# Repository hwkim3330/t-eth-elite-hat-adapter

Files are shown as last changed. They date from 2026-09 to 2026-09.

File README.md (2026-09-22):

# T-ETH-Elite ↔ Raspberry Pi HAT adapter

Hardware that lets a **Raspberry Pi HAT** run on a **LilyGO T-ETH-Elite**
(ESP32-S3) instead of a Pi. Built for one specific HAT — TSN Lab's
`10BASE-T1S HAT` (Microchip LAN8651, [devicemart #15980354](https://www.devicemart.co.kr/goods/view?no=15980354)),
which is a Pi-only product — so that a 10BASE-T1S node can be an ESP32 rather
than a Raspberry Pi. Firmware side lives in
[esp32-t1s-bridge](https://github.com/hwkim3330/esp32-t1s-bridge).

```
   TSN Lab 10Base-T1S HAT  (LAN8651)
   ── adapter PCB ──                    pcb/
   LilyGO T-ETH-Elite  (ESP32-S3)
   ── printed tray ──                   case/
```

| | |
|---|---|
| `pcb/` | the adapter board — KiCad project, gerbers, BOM/CPL |
| `case/` | printed base tray for the Elite, generated and clearance-checked by script |
| `reference/` | LilyGo's own DXF and 3D models, plus the script that re-derives every dimension from them |
| [`pcb/GEOMETRY.md`](pcb/GEOMETRY.md) | **the single source of truth** — every measured number, with its provenance |

## The short version of why this exists

Plugging the HAT straight onto the T-ETH-Elite *almost* works, and the two
reasons it doesn't are worth stating up front:

1. **Electrically it already works.** LilyGo wired the Elite's 40-pin header to
   the standard Raspberry Pi GPIO assignment, pin for pin. No level shifting,
   no remapping, nothing to translate. The adapter carries no signal logic at
   all — the connection is the stacking header's own pins, straight through.
2. **The near mounting holes already line up.** Deriving where a Pi's
   header-end holes must sit, from the Elite's own header position, lands on
   the Elite's own bottom hole pair to within **0.005 mm**. Same holes.
3. **But the RJ45 is in the way.** The Elite's RJ45 stands **15.97 mm** off the
   PCB while its header pins stop at **10.10 mm**. Any flat, un-notched board
   dropped onto that header — which is exactly what a standard Pi HAT is — hits
   the jack 5.87 mm before it seats. LilyGo's own shields cut a notch for it.
4. **And the far mounting holes fall off the end.** A HAT's far holes sit 49 mm
   from the near pair, i.e. at y = 53.63 in the Elite's frame — past the Elite's
   own board edge at 49.19. There is nothing there to screw into.

Of those, only (4) genuinely needs a board. A tall enough stacking header would
lift a HAT clear of the RJ45 on its own — so the honest claim is not "a HAT
cannot sit on this board", it is that without the adapter a HAT sits on **two
screws at the connector end and nothing at the other**, with the Elite's BOOT
and RESET switches buried underneath it. On a board you push terminal-block
levers into, that is the difference between a fixture and a wobble.

## Provenance

Nothing here was scaled off a drawing by eye. The mounting holes, the 40-pin
grid, the outline notches and the component heights all come out of LilyGo's own
published DXF and 3D CAD, cross-checked three ways — and the hole pattern was
independently validated against a real board on a laser-cut plate in
`~/stl-model/acrylic-frame`. `reference/measure.py` re-derives the whole set
from the vendor files, so the numbers can be audited rather than trusted:

```bash
pip install --user ezdxf trimesh manifold3d py7zr
python3 reference/measure.py
```

The one number that is *not* from CAD is the HAT's own 58 × 49 hole pattern,
which is inferred from a product photo (method and error bars in
[`pcb/GEOMETRY.md`](pcb/GEOMETRY.md)). Only the placement of the adapter's two far holes depends
on it.

## Status

Designed, checked, **never built**. No board has been fabricated, nothing has
been printed, and no part of the stack has been assembled or powered. The
clearance check the case script runs is against LilyGo's model, not against a
real board. Read the "not verified" sections in [`pcb/README.md`](pcb/README.md) and
[`case/README.md`](case/README.md) before spending money.

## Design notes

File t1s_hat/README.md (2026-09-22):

# T1S HAT — LAN8651 10BASE-T1S for the LilyGO T-ETH-Elite

Our own 10BASE-T1S board for the [LilyGO
T-ETH-Elite](https://github.com/Xinyuan-LilyGO/LilyGO-T-ETH-Series)
(ESP32-S3), built around a **Microchip LAN8651** MAC-PHY. It replaces buying
TSN Lab's ready-made HAT: same chip, same host header, our schematic.

Two source files govern this board and **nothing here re-derives a number in
either of them**:

| file | governs |
|---|---|
| [`ELECTRICAL.md`](ELECTRICAL.md) | every component, value and pin-handling rule, each quoted from Microchip DS60001734F or AN1718 (DS60001718D) |
| [`../pcb/GEOMETRY.md`](../pcb/GEOMETRY.md) | outline, mounting holes, 2×20 grid — measured from LilyGo's own DXF and 3D CAD |

Everything is generated by [`make_t1s_hat.py`](make_t1s_hat.py), which emits
the symbol library, the two project-local footprints, the schematic and the
PCB, then reads the board back and asserts every mechanical feature against
`GEOMETRY.md`.

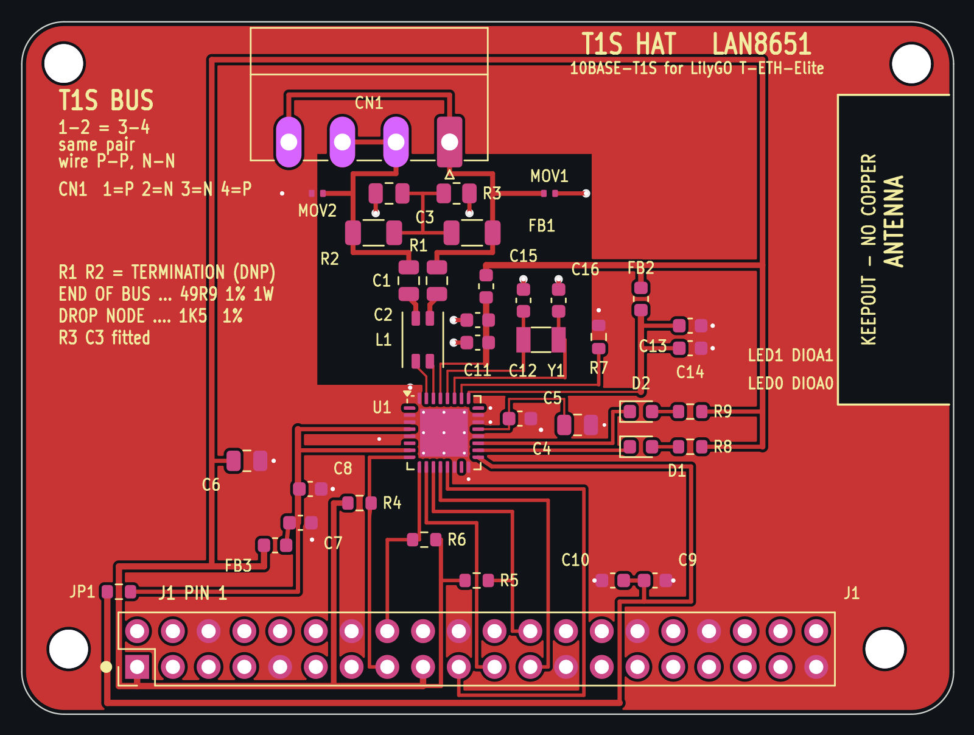
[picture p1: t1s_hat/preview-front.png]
front


## What it is

- **LAN8651**, 32-VQFN 5×5, single 3.3 V rail (the '51 regulates its own 1.8 V
  core, so there is no second regulator and no sequencing diode).
- **OPEN Alliance TC6 SPI** to the host on the same header pins TSN Lab's
  device-tree overlay uses, so their SDK and the mainline `microchip,lan8651`
  driver both work unmodified if this board is ever put on a Pi.
- **Bus interface network** in AN1718's MINIMAL BIN order: common-mode choke →
  AC coupling caps → termination → ESD → 4-way 3.81 mm pluggable terminal
  block, wired so the node taps a daisy chain.
- 38 parts, 4 of them deliberately unstuffed. One of the 38 is a 0 Ω jumper,
  and it is a design decision, not an accident — see below.

## The two parts that had to be chosen, not assumed

Both are drawn from their own data sheet into
[`fp/t1s_hat.pretty`](fp/t1s_hat.pretty), generated by `make_t1s_hat.py`
alongside the board, and the generator asserts the pad count and the overall
land size back out of the finished `.kicad_pcb`.

### L1 — TDK **ACT1210L-201-2P-TL00**, LCSC **C131444**

AN1718 names ACT1210D-131-2P-TL00, ACT1210E-241-2P-TL00 and Murata
DLW32MH241MX2, and says in the same breath that *"exact component part numbers
and parameters must be determined by the customer's unique application
requirements"* — they are examples. All three are **3.2 × 2.5 mm** (EIA 1210)
2-line chokes in the 130…240 µH @ 100 kHz band. The board previously sat on
KiCad's `Inductor_SMD:L_CommonMode_Wurth_WE-CNSW-1206`, a **3.2 × 1.6 mm**
land: same length, 0.9 mm too narrow, so the real part's terminals miss the
pads. KiCad ships no 4-terminal common-mode choke land in 3225.

The part fitted instead is the **ACT1210L-201-2P-TL00**: same ACT1210 package,
200 µH @ 100 kHz — inside the span AN1718's own examples cover — 70 mA,
5.5 Ω, AEC-Q200, and, unlike all three examples, **stocked at LCSC**
(C131444, ~$0.39/1k), which is where this board gets built.

Its land is `t1s_hat:L_CommonMode_TDK_ACT1210_3225`, drawn from TDK's ACT1210
data sheet "Layout recommendation" (drawing IND1512-9): **4.1 mm overall
across the pads with a 2.0 mm gap between the columns**, so each pad is
1.05 mm long on a 3.05 mm pitch, and **1.6 mm overall across the rows with a
0.4 mm gap**, so each pad is 0.60 mm wide on a 1.0 mm pitch. Body from the
same sheet: 3.2 ±0.2 long, 2.5 ±0.2 wide, 3.9 max over the terminals.

The symbol changed with it: the ACT1210's windings are **1-4 and 2-3**
(pin configuration and circuit diagram, same sheet), which is
`Device:L_Coupled_1423`, not the `…_1243` the 1206 Würth part needed.

### MOV1 / MOV2 — TDK **AVRH10C221KT1R5YA8**, LCSC **C2157827**

This is the part `ELECTRICAL.md` already names, and it is a **1005 [0402]**
chip varistor — 1.0 × 0.5 × 0.5 mm, 220 V V1mA, 70 V DC, **1.5 pF**, 25 kV per
IEC 61000-4-2. The board had it on `Resistor_SMD:R_1206_3216Metric`: three
size codes too big. It is now on `t1s_hat:Varistor_TDK_AVRH10_1005`, from the
recommended land pattern in TDK's automotive AVR chip-varistor catalogue
(pad 0.35…0.45 long, gap 0.3…0.5, pad 0.4…0.6 wide — the middle of each:
**0.40 long, 0.40 gap, 0.50 wide**). KiCad's `R_0402_1005Metric` is 0.54 ×
0.64 on a 1.02 mm pitch, outside all three ranges, which is why this one is
drawn here too. Both parts stay **DNP**; the land is now a real one.

## Three decisions that are not in ELECTRICAL.md / GEOMETRY.md

These were directed after those files were written. They are marked
`DIRECTED:` in the generator, and the reasoning is recorded here.

### 1. Two layers, not four

`ELECTRICAL.md` calls 4 layers non-negotiable because AN1718 wants TRXP/TRXN
as length-matched, impedance-controlled 50 Ω single-ended traces, and 50 Ω on
2-layer 1.6 mm FR4 needs a ~2.9 mm trace. The width figure is right; the
conclusion does not follow at this speed and length. 10BASE-T1S runs at
12.5 MBd with deliberately slow, EMC-shaped edges, and the run from the QFN to
the connector here is ~20 mm — electrically short, well under the length at
which a mismatch on a trace this short costs anything at these edge rates.
AN1718's 50 Ω line is a "do this and you are safe" recommendation, not a
threshold this design crosses.

**So the impedance is not controlled and is not claimed to be.** The pair is
0.35 mm over 1.51 mm of FR4, which is nowhere near 50 Ω. What buys the margin
back instead is layout discipline, and those rules are treated as hard:

- **All signal routing is on F.Cu. B.Cu is an uninterrupted ground pour.**
  The generator asserts this — `verify()` counts B.Cu tracks and the table
  prints `B.Cu signals … 0 tracks`.
- The only two interruptions in that plane are the antenna keepout and the
  all-layer void under the choke, both of which AN1718 or the Elite requires,
  and the choke void is sized to the choke — see inference 8.
- The one crossing that a single signal layer could not absorb is a **0 Ω
  jumper on F.Cu**, not a via pair through the plane. See below.
- TRXP/TRXN are short, symmetric about x = 29.0 from the QFN to the connector,
  and carry **no vias**.

Moving to 4 layers with a dedicated reference plane is the fallback if EMC
measurements later ask for it. It is not a cost compromise.

### 2. No RJ45 notch — the outline is a plain rectangle

`GEOMETRY.md`'s notch exists because a board ~13 mm above the Elite would foul
the RJ45, which stands 15.97 mm. This board is lifted clear of the jack by a
taller riser instead, so nothing has to be cut away. Outline is the full
**66.22 × 49.19 mm rectangle, 3 mm corners**. Everything else mechanical in
`GEOMETRY.md` is unchanged and still authoritative: the four asymmetric
mounting holes and the 2×20 grid.

That is also what makes the 2-layer decision work — the notch was the largest
interruption in the bottom-side ground pour, right where the pair and its
choke want a clean reference.

### 3. The connection is two-stage — read this before ordering parts

```
   T1S HAT  (this board)
        ↑ its 2x20 socket goes on the riser's long pins
   ── 2x20 stacking riser ──          ≈18-20 mm total, set by the riser
        ↑ riser socket swallows the Elite's own 9.30 mm pins
        ↑ RJ45 (15.97 mm) passes beside the stack, not through a notch
   LilyGO T-ETH-Elite (ESP32-S3)
```

**A single tall stacking header does not work here.** The Elite's pins are
only 9.30 mm long; they would reach barely halfway up a ~17 mm barrel whose
contacts sit near the top. You need a **riser** (a 2×20 stacking header that
plugs onto the Elite and presents longer pins) plus this board's **socket**.
That is a real failure mode someone will otherwise hit at the checkout page.

Board height above the Elite PCB is **assumed ≈18–20 mm**, set by the riser.
Nothing on this board depends on the exact number.

## Stack-up assumed

JLCPCB's standard 2-layer 1.6 mm FR4 build, written into the board file:

| layer | | thickness |
|---|---|---|
| F.Cu | signals + GND flood | 0.035 mm (1 oz) |
| core | FR4, εr ≈ 4.5 | 1.510 mm |
| B.Cu | **ground plane, nothing else** | 0.035 mm (1 oz) |

Design rules: 0.15 mm minimum clearance and track, 0.45 mm minimum via
(0.25 mm drill), 0.20 mm minimum through-hole drill — the last one because the
stock `…_ThermalVias` QFN footprint uses 0.20 mm holes under the exposed pad.

## Termination stuffing — the one thing an assembler must decide

The board **ships with R1/R2 unstuffed**, per `ELECTRICAL.md` ("footprints
fitted, DNP by default — stuff per where this node sits on the bus"). The
silkscreen carries the table:

| where this node sits | R1, R2 |
|---|---|
| **end of the bus** | 49R9 1 % 1 W 1206 |
| **interior drop node** | 1K5 1 % 1206 |

`R3` (100 k) and `C3` (100 nF) — AN1718's common-mode termination — **are
fitted**. ESD elements MOV1/MOV2 have footprints and are DNP; `ELECTRICAL.md`
calls them optional.

`CN1` is wired **P N N P**, and the silkscreen carries that as a legend
(`CN1 1=P 2=N 3=N 4=P`) in the clear area to its left. Per-pad letters were
dropped: the four pads are 1.8 × 3.6 mm ovals with the connector's own body
outline 0.9 mm below them and R3/C3 0.6 mm below that, leaving a 0.6 mm slot —
nowhere to letter a pad without printing on copper. Pins 1–2 and 3–4 are the
same pair with opposite orientation, so wire P to P and N to N rather than
pin-for-pin. That order is what lets both on-board links be drawn without a
crossing.

## Verified

- **Mechanical: worst error 0.00000 mm** against `GEOMETRY.md`, tolerance
  0.01 mm, over the outline, all four mounting holes and all 40 header pads.
  `make_t1s_hat.py` prints the full table and exits non-zero on any failure.
- **Antenna keepout clean.** The generator walks every track, via, footprint
  and *filled zone polygon* on both layers and counts anything inside
  x 58…66.22, y 22…44: **0 intruders.** The keepout is a rule area that forbids
  copper, tracks, vias, pads and footprints on both layers, so both pours are
  cut out there. Silkscreen (ink, not copper) does mark the window.
- **B.Cu carries 0 signal tracks.**
- **Unrouted connections: 0.**
- **L1 and MOV1/MOV2 lands read back as 4.10 × 1.60 mm on 4 pads and
  1.20 × 0.50 mm on 2 pads** — the data sheet numbers above, asserted out of
  the board file, not just written into it.
- **ERC: 0 errors, 5 warnings** — see below.
- **DRC: 0 errors, 4 warnings** — see below.

### ERC — 0 errors

`kicad-cli` 7.0.11 has no `sch erc` subcommand, only `export`, so ERC is run
through the real eeschema on an Xvfb display by
[`run_erc.sh`](run_erc.sh), with **Show: All and Exclusions both ticked**
before the run. Report as produced: [`erc.rpt`](erc.rpt).

```
** ERC messages: 5  Errors 0  Warnings 5
```

All 5 warnings are the same thing: *"Pins of type Bidirectional and Power
output are connected"* on U1 pins 20, 22, 23 (DIOA2/3/4) and 16, 14
(DIOB0/DIOB1). Those are the unused configurable IO tied to ground, which is
exactly what the data sheet says to do — *"When not used, these pins may be
connected directly to ground."* Nothing is excluded or suppressed.

### DRC — 0 errors, 4 warnings

Run through `pcbnew.WriteDRCReport()` (same engine; `kicad-cli` has no
`pcb drc` either). Report as produced: [`drc.rpt`](drc.rpt).

```
** Found 4 DRC violations **
** Found 0 unconnected pads **
** Found 0 Footprint errors **
```

**Zero errors of any kind** — no clearance, hole, courtyard, keepout,
solder-mask, silkscreen or unconnected-pad violation. All four remaining
warnings are the same one:

| count | what |
|---|---|
| 4 | `lib_footprint_issues` — the four Ø2.75 mounting holes are generated inline and belong to no footprint library, so the library-consistency test has nothing to compare them to (same as `../pcb/`) |

Nothing is excluded. Running it yourself reproduces exactly this.

## Two crossings on one layer, and how they were closed

The host bundle is **not planar on one layer**. With the LAN8651's pin order
(IRQ 9, SDO 10, CS_N 11, SCLK 12, SDI 13, left to right along the QFN's bottom
edge) and `ELECTRICAL.md`'s header assignment (IRQ→16, MOSI→19, MISO→21,
SCLK→23, CS_N→24), SDI/MOSI starts at the right-hand end of the QFN and has to
reach the left-hand end of its target group, so it must cross the other four.
MOSI takes the long way round — out to x = 39.9, down, and back along a 2 mm
band under the header — which resolves that crossing, but the loop it traces
then encloses the CS_N column, and 3V3 enters the board outside that loop.
VDDP is fenced in the same way, by the +3V3 tree, the header row and the SPI
fan-out. That left one crossing on each of two nets.

**B.Cu was not used for either.** The uninterrupted bottom pour is the thing
buying back the fourth layer on this design; `B.Cu signal tracks: 0` is still
asserted by the generator and still true.

### `SPI_CS_N` — closed by moving R5, no new part

R5 (the 10 k CS_N pull-up) moved from (50, 12.4) to **(32.326, 9.5)**, where it
sits **astride the SPI_MISO column**: MISO runs vertically between R5's own two
pads. A 0603's pads are 0.85 mm apart, so a 0.25 mm track through the middle
keeps 0.30 mm to each — the textbook 2-layer crossover, except that the part
doing the hopping is one that had to be in the CS_N path anyway. Its 3V3 now
comes off the column that already feeds R6, and its CS_N leg lands straight on
the CS_N column. Cost: zero extra parts.

### `VDDP` — closed by JP1, a real 0 Ω jumper

There is no equivalent trick for VDDP: its two halves are both VDDP, and no
VDDP-to-VDDP part existed to hop with. So **JP1, a 0 Ω 0603, is fitted at
(6.9, 8.7)**, straddling the +3V3 branch that climbs the left edge — +3V3
passes between its pads. It is a real part, and it is real everywhere:

- in the schematic, as `Device:R`, with the net split either side of it
  (`VDDP` on the pin-7 island, **`VDDP_17`** on the pin-17 island, each with
  its own PWR_FLAG so ERC sees both as supplied);
- in [`bom.csv`](bom.csv) and [`cpl.csv`](cpl.csv), `Populate = fit`, described
  as *"FITTED — the board does not work without it"*;
- on the silkscreen, designator `JP1`, like every other part.

From JP1 the link runs round the outside of the header in the free ~1 mm lane
below it and climbs back between two pad columns at x = 42.486. Nothing else
goes under the header there: the +3V3 rail stops at y = 2.0 and MOSI's return
at y = 1.35, and both turn upward before that lane. It is a long way round —
the VDDP_17 net totals 84 mm of 0.30…0.45 mm track, about 0.1 Ω, ~3 mV at
50 mA — and each island keeps its own 0.1 µF + 0.01 µF at the pin, so the
length costs nothing that matters. **The short way round does not exist on one
layer**; the alternative was a via pair through the ground plane, which this
design does not spend.

## Silkscreen — 48 violations to 0

The silkscreen exists so the board can be assembled and debugged, and it was
not doing that job: designators sat on pads and on each other (`R3` across the
connector, `C1`/`C2` over pads, `MOV2` into `CN1`).

| | before | after |
|---|---|---|
| `silk_overlap` | 28 | **0** |
| `silk_over_copper` | 15 | **0** |
| `silk_edge_clearance` | 5 | **0** |
| designators dropped | — | **0 of 38** |

Library footprints put their reference wherever the library author did, which
on a board this dense is wherever the neighbour already is. They are placed by
the generator instead: `place_references()` tries each designator in a ring of
candidate positions around its own part — horizontal first, sideways only if
nothing horizontal fits — and keeps the first that clears every pad, via, ink
and the board edge. A part with nowhere legible left would lose its
designator rather than print an unreadable pile; in the end none had to.
Three positions are hinted (`J1`, `U1`, `R1`, `Y1`) because the ring around a
large or boxed-in part lands somewhere silly, and a hint still has to pass the
same clearance test as any other candidate.

Four other things moved with it:

- **Board text** was re-laid into the two areas that carry no pads — the strip
  left of the bus network and the top-right corner — and shortened to fit
  clear of CN1's body outline.
- **CN1's per-pad P/N letters** became one legend line; see above.
- **The J1 pin-1 marker** is a filled dot outboard of pin 1, not a stroked
  triangle above it. Above is where JP1 has to sit, and the triangle's three
  legs also overlapped *each other* at the apex — one filled shape cannot.
- **CN1 moved 0.35 mm inboard** (y 41 → 40.65): its body outline otherwise
  lands 0.02 mm from `Edge.Cuts`, and the keepout window's ink now stops
  0.32 mm short of the board edge instead of running onto it.

## Inferences — things not taken from the spec files

Flagged because they are judgement, not quotation:

1. **U1 pin 1 (INH) is left unconnected.** `ELECTRICAL.md`'s pin-handling
   table does not cover INH. DS60001734F Table 3-5 says *"When not used, this
   pin should be left unconnected"*, so it is, with no copper stub.
2. **L1 is a 200 µH part where AN1718's examples are 130 and 240 µH.**
   AN1718 gives no minimum or maximum, only three example part numbers and an
   instruction to pick for the application; 200 µH is inside the span they
   cover and is the value TDK itself lists for one-pair automotive Ethernet.
   The land pattern is quoted, not inferred — but the *choice of value inside
   that span* is judgement.
3. **The 0 Ω jumper JP1 and the net split `VDDP` / `VDDP_17`** are a layout
   decision, not something either spec file asks for. `ELECTRICAL.md` treats
   VDDP as one net; on this board it is one net with a 0 Ω link in it.
4. **The crystal is a 2-pin 3.2 × 1.5 mm package** (`Crystal_SMD_3215-2Pin`),
   not a 4-pin grounded-case one. `ELECTRICAL.md` specifies 25 MHz,
   fundamental, parallel, CL 18 pF and says nothing about the package; the
   2-pin part routes cleanly here. A grounded-case 3225 is better for EMC and
   is a footprint swap.
5. **XTI is declared `passive` in the LAN8651 symbol**, not `input`. It is an
   oscillator pin driven by a passive crystal; declaring it an input makes
   KiCad's `pin_not_driven` test fire on a net that has no driver by design.
   Common practice, but it is a choice.
6. **The 40-pin header is a project-local symbol**, `t1s_hat:HAT_HEADER_2x20`,
   not `Connector_Generic:Conn_02x20_Odd_Even`. Its pins carry real electrical
   types (the six host signals are `output`/`input`, everything else
   `passive`), because the ESP32 side really is the driver and the generic
   connector's all-passive pins make ERC report every SPI input as undriven.
   The **footprint** is the stock `PinHeader_2x20_P2.54mm_Vertical`.
7. **Header pin 1 is at the low-x end, odd pins on the y = 3.360 row.**
   Inherited from `../pcb/`, where it is derived (not measured) from the Pi
   convention and from USB_DN/DP on pins 35/37 routing to the Elite's
   right-hand USB-C. Affects silkscreen only.
8. **`BIN_VOID` = x 21…40.5, y 23.4…39.8** and **`CMC_VOID` = x 26.90…30.10,
   y 24.40…28.80.** AN1718 asks for "a void in the ground flooding on the
   outside layer surrounding the BIN" and "an all-layer void underneath the
   CMC" **without giving dimensions**, so both sizes are judgement. The first
   follows the BIN components. The second is the only place other than the
   antenna window where the B.Cu reference plane is cut, so it is sized to the
   part and no further: **the ACT1210's maximum body — 3.9 mm over the
   terminals × 2.7 mm wide (2.5 + tolerance) — plus 0.25 mm a side**, giving
   3.2 × 4.4 mm (L1 is rotated 90°, so the 3.9 runs along y). The margin
   covers placement tolerance and nothing else; the body is what couples to
   the plane, because the body is the core. That also covers the 4.1 × 1.6 mm
   land with room to spare. The void grew in x against the old number above,
   not because the margin grew but because the part did: the 1206 land it used
   to be sized around was the wrong part. C11/C12 moved 0.8 mm outboard so
   their ground vias stay clear of it.
9. **The T1S pair necks to 0.15 mm at the QFN.** The package puts TRXP and
   TRXN 0.5 mm apart; AN1718's "3× trace width centre-to-centre to other
   signals" cannot be met between the pair's own two legs at a 0.5 mm-pitch
   QFN, and Microchip's own EVB does not either. It **is** met against every
   other net, by the F.Cu void around the BIN.
10. **Pair length match ≈0.2 mm.** TRXN opens out to the choke before TRXP
    does (so the gap only ever grows), which costs about 0.2 mm of mismatch —
    roughly 1.2 ps. Not measured on hardware.
11. **The stackup numbers** (1.51 mm core, εr 4.5, 1 oz outer copper) are
    JLCPCB's standard 2-layer build, taken as the assumption, not measured.

## Files

| file | what |
|---|---|
| `ELECTRICAL.md` | **electrical source of truth** |
| `make_t1s_hat.py` | generator: symbol lib → schematic → PCB → verify → DRC → exports |
| `run_erc.sh` | runs eeschema's ERC headlessly (Xvfb + xdotool) and saves the report |
| `fill_zones.sh` | fills the zones through pcbnew's GUI — `ZONE_FILLER` segfaults in KiCad 7.0.11's Python bindings |
| `t1s_hat.kicad_sch` / `.kicad_pro` / `sym-lib-table` / `fp-lib-table` | schematic + project |
| `sym/t1s_hat.kicad_sym` | **LAN8651** (33 pins incl. the exposed pad) and the host header — neither exists in KiCad's libraries |
| `fp/t1s_hat.pretty/` | the TDK ACT1210 choke land and the TDK AVRH10 varistor land, each from that part's own data sheet — KiCad ships neither |
| `t1s_hat.kicad_pcb` | the board |
| `gerbers/t1s_hat_gerbers.zip` | fab-ready: 8 gerber layers, separate PTH/NPTH Excellon, drill maps, job file |
| `bom.csv` / `cpl.csv` | BOM (with a `Populate` column) and position file |
| `preview-front.png/.svg`, `preview-back.png/.svg` | both sides |
| `erc.rpt` / `drc.rpt` | reports as produced, nothing excluded |

Regenerate with `python3 make_t1s_hat.py`. Geometry is reproducible to the
internal unit, but the output is not byte-reproducible — KiCad stamps fresh
UUIDs and timestamps on every run. Compare the printed coordinate table, not
the files.

Drill files and `cpl.csv` are plotted against the drill/place origin, which the
generator puts on `GEOMETRY.md`'s own origin, so `NPTH.drl` literally reads
`X3.33Y4.63` and `cpl.csv` reads `8.196, 3.360`.

## Bottom side — clear area for a later variant

The board now sits ~18–20 mm above the Elite, so **the bottom is usable**:

| region | clearance below |
|---|---|
| everywhere except the RJ45 footprint | ≈14 mm or more |
| over the RJ45, x −5.18…16.42, y 10.50…28.90 | **much less** — the jack tops out at 15.17 mm above the Elite's PCB |
| under the 2×20 socket, y 0…9 | occupied by the socket body |

Nothing is placed on B.Cu on this board (it is the ground plane). A radar
variant wanting that space should stay clear of the RJ45 column and of the
header, and must not slot the plane under the bus pair.

## What is NOT verified — read before ordering

- **Nothing has been bench-tested.** No board, no Elite, no riser in hand.
- **The two project-local lands are transcribed from data sheets, not
  measured.** L1's came from TDK's ACT1210 layout recommendation and MOV's
  from TDK's AVR catalogue; the generator asserts that what is in the board
  file matches what was transcribed, which is not the same as asserting that
  the transcription is right. Both are worth one look at the PDF before fab —
  they are the only two lands here that KiCad did not supply.
- **LCSC stock and part status were read from the catalogue, not ordered
  against.** C131444 (L1) and C2157827 (MOV1/2) were in stock when this was
  written; neither is confirmed as a JLCPCB *basic* part, so expect an
  extended-part fee or hand-placement for L1.
- **Impedance is not controlled** and the 50 Ω figure in `ELECTRICAL.md` is
  deliberately not met; see the 2-layer decision.
- **Oscillator margin was not calculated.** `ELECTRICAL.md` asks for >10; that
  depends on the crystal's ESR and C0, which are not fixed to a part number.
- **The riser is specified by class, not part number**, and it sets the stack
  height. Pick it before the standoffs.
- **No order was placed.** The deliverable is fab-ready files to upload.

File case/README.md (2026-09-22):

# Printed base tray for the T-ETH-Elite

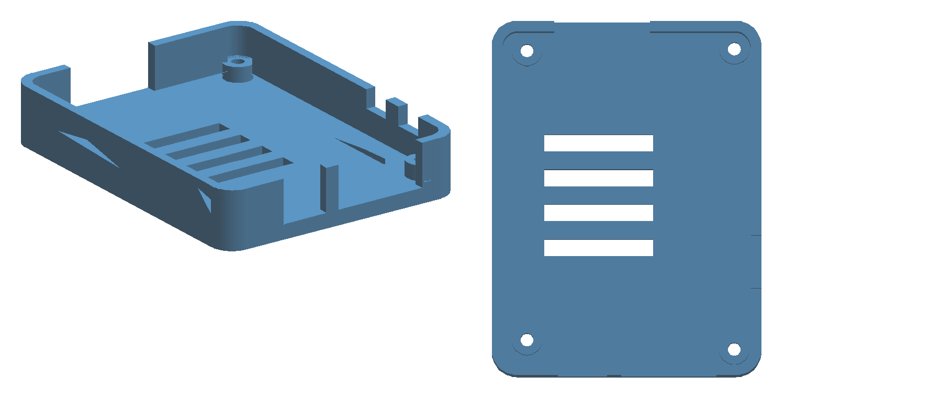
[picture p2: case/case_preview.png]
preview


```bash
pip install --user trimesh manifold3d
python3 case.py            # -> case_bottom.stl, plus the clearance report
python3 case.py --check    # report only
```

The tray the bottom board of the stack drops into:

```
   TSN Lab 10Base-T1S HAT          open, not enclosed - see below
   ── adapter PCB ──               ../t_eth_elite_hat_adapter/
   LilyGO T-ETH-Elite
   ── this tray ──
```

71.0 × 54.0 × 12.4 mm, 14.3 cm³, watertight, one part, no supports needed if
printed floor-down.

## Why a tray and not a box

The two lower boards have published CAD, so a part built against them can be
*checked* — `case.py` boolean-intersects the finished tray with LilyGo's own 3D
model of the Elite and refuses to pass if anything overlaps. The T1S HAT on top
has no published CAD; its size is known only from a product photo, and its
terminal block, rotary node-ID switch and wake/sleep button all have to stay
reachable anyway. Enclosing that from photo-derived numbers would be guessing
dressed up as a design, so the tray stops below it.

## What the shape is actually doing

Every opening exists because of a specific part measured out of LilyGo's model
(see `../pcb/GEOMETRY.md`):

| feature | why |
|---|---|
| left wall removed, y 10.0…29.4 | the RJ45 overhangs the PCB edge by 5.18 mm and dips 1.43 mm below it — a lowered wall would not clear it, it has to be gone |
| right wall opening, y 10.8…20.7 | USB-C, overhangs by 1.13 mm |
| right wall opening, y 23.4…42.7 | the WROOM antenna — LilyGo cut their own PCB away here, so no plastic against it either |
| far wall notched above z 2.0, at the two switch footprints | BOOT and RST. They are poked from above through the adapter's Ø4 holes; this lets a tool also come in from the side |
| 3.2 mm standoff under the PCB | the microSD socket hangs 2.06 mm below the board, the RJ45 1.43 mm |
| floor slots | vents, and less plastic |

## Hardware

Four M2.5 screws, long enough to go through the tray floor, the boss, and the
Elite's own hole, and bite into a female standoff above the board:

```
   adapter PCB
   ═══════════   M2.5 screw down from above
   [standoff]    M2.5 female-female, ≈13 mm - set by the stacking header, measure it
   ─ Elite PCB ─
   [boss 3.2]
   ═══════════   M2.5 screw up from below, head sunk in the Ø5.5 × 2.0 counterbore
   tray floor
```

The tray's holes are Ø2.7 clearance, not pilot holes — the screw passes
through, it does not thread into the plastic.

Standoff length is deliberately not specified here. It follows from whichever
2×20 stacking header gets fitted to the adapter, and that part has not been
bought yet. Measure the header, then buy standoffs.

## Verified / not verified

Verified, by `case.py` on every run:

- watertight solid, single body
- all four bosses land on the Elite's own asymmetric hole pattern
- **zero interference** with LilyGo's 3D model of the board: no overlap with any
  of its 35 solid bodies, and of 141 422 model vertices none fall inside the
  tray. (The check does flag 522 vertices sitting 0.012–0.025 mm inside — those
  are the zero-thickness copper-layer sheets the model draws 0.02 mm outside the
  substrate, which is an order of magnitude below anything a printer resolves.
  The script identifies that case explicitly rather than widening a tolerance
  until it passes.)

Not verified:

- **Never printed.** No dimensional check against a real board, no test of
  whether the 0.4 mm edge clearance is right for your printer.
- Wall height (6.0 mm above the PCB) is chosen to stay well under the adapter,
  which sits ≈13 mm up. That number comes from LilyGo's own shield, not from a
  header part anyone has in hand.
- No lid, no HAT enclosure — deliberately, see above.

## Mounting it to something

`DECK` at the top of `case.py` is `None`. Set it to `(35.0, 45.0)` to add the
plate-B deck hole pattern from `~/stl-model/acrylic-frame`, so this bolts onto
the same laser-cut rig as the other boards there.

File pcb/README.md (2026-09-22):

# T-ETH-Elite → Raspberry Pi HAT adapter

A passive spacer/notch board that lets a real Raspberry Pi HAT — specifically
TSN Lab's **10BASE-T1S HAT (LAN8651)** — sit on a
[LilyGO T-ETH-Elite](https://github.com/Xinyuan-LilyGO/LilyGO-T-ETH-Series)
(ESP32-S3) instead of on a Pi.

One connector, six mounting holes, two tool-access holes, **no traces, no
zones, no nets**. Every number on the board comes from
[`GEOMETRY.md`](GEOMETRY.md), which was measured from LilyGo's own DXF and 3D
CAD and cross-checked against two more independent sources. That file is the
source of truth; the board is generated from it by
[`make_board.py`](make_board.py).

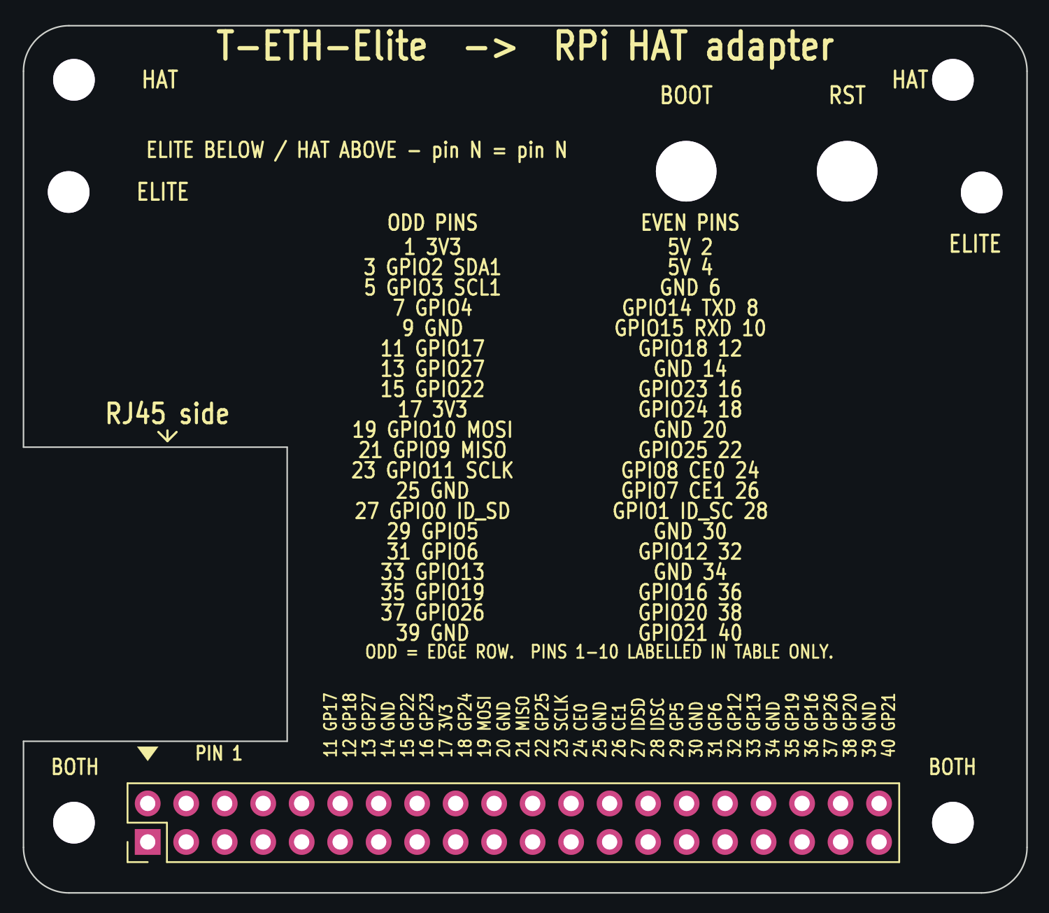
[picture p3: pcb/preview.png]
board


## Why this board exists at all

Not for pin mapping. The T-ETH-Elite's 40-pin header is already a Raspberry Pi
header, and — this is the part worth stating plainly — **its geometry already
matches the Pi's too**. Deriving the Pi near-hole positions from the header
alone (field centre 32.326 ± 29.0, y = the header centre 4.63) gives
(3.326, 4.63) and (61.326, 4.63); the Elite's own bottom mounting holes are at
(3.33, 4.63) and (61.33, 4.63). **0.005 mm.** A HAT would bolt straight onto
those two holes with nothing in between.

What stops it is height:

| part on the Elite | top (LilyGo CAD z) | above the PCB surface |
|---|---|---|
| **RJ45 with magnetics** | **15.97 mm** | 15.17 mm |
| 40-pin header pins | 10.10 mm | 9.30 mm |

(CAD centres the 1.575 mm PCB on z = 0, so its top face is 0.80. The gap that
matters is a difference and is the same either way.)

**The RJ45 stands 5.87 mm proud of the tallest pin.** A HAT pushed onto that
header fouls the jack long before its socket seats, because a standard HAT is a
flat rectangle spanning the left half of the board. LilyGo hit the same wall on
their own LoRa/LTE/Gateway shields and cut a notch for it.

Be precise about what follows from that, though: **a tall enough stacking
header would lift a HAT clear of the RJ45 on its own**, no adapter needed. What
it would not solve is the mounting. A HAT's far hole pair sits 49 mm from the
near pair, i.e. at y = 53.63 — past the Elite's own edge at 49.19, with nothing
underneath it. So the HAT would hang off two screws at the connector end, on a
board whose T1S terminal block you push and pull levers into.

What this board actually buys you, in order of how hard they are to get
otherwise: **the far mounting pair** (four-corner support), **BOOT/RST access**
through a board that would otherwise bury both switches, and the notch.

## Stack-up

```
   TSN Lab 10BASE-T1S HAT (LAN8651)
        ↑ plugs onto the pins protruding above this board
   ── this adapter ──                    ≈13 mm above the Elite PCB
        ↑ stacking-header socket swallows the Elite's 9.30 mm pins
        ↑ RJ45 (15.97) passes up through the notch
   LilyGO T-ETH-Elite (ESP32-S3)
```

## The board

- **Outline** 66.22 × 57.20 mm, 3 mm rounded corners, 2-layer, 1.6 mm.
  Same width as the Elite, extended 8.0 mm in +y so it can carry the HAT's far
  mounting holes, which land past the Elite's own edge.
- **RJ45 notch** x 0…17.40, y 10.00…29.40 — a rectangular bite out of the left
  edge, deliberately ~0.5 mm looser all round than the RJ45's measured
  envelope. That region is empty board here, so the clearance is free.
- **Six Ø2.75 non-plated holes** (M2.5 free fit):

  | ref | position | serves |
  |---|---|---|
  | H1 | (3.33, 4.63) | Elite bottom-left **and** HAT near-left |
  | H2 | (61.33, 4.63) | Elite bottom-right **and** HAT near-right |
  | H3 | (2.98, 46.23) | Elite top-left |
  | H4 | (63.23, 46.20) | Elite top-right |
  | H5 | (3.33, 53.63) | HAT far-left |
  | H6 | (61.33, 53.63) | HAT far-right |

  **H1/H2 are shared between the Elite and the HAT on purpose** — see the
  0.005 mm above. One pair of holes is drilled, not two. Silkscreen marks
  which is which: `BOTH` / `ELITE` / `HAT`.

  The Elite's four holes are **not a rectangle**: 58.00 mm apart at the bottom,
  60.25 mm at the top. That asymmetry is real LilyGo design (three independent
  files agree to <0.1 mm) and it is useful — the pattern is self-keying, so
  this board physically cannot be bolted on rotated 180°.

- **Two Ø4.0 non-plated tool holes** at (43.73, 47.60) `BOOT` and
  (54.35, 47.60) `RST`, over the Elite's two ST-1133 tactile switches
  (SW4 = BOOT, SW5 = EN/RESET), which this board would otherwise bury. Centres
  are the midpoints of the switch bodies in LilyGo's CAD. Ø4.0 is a
  tweezer/pen tip, not a finger.

- **One 2×20 THT connector**, pins on x = 8.196 + 2.54·k (k = 0…19),
  y = 3.360 and 5.900. Plated through-holes, Ø1.0 drill / Ø1.7 pad, annular
  rings both sides — the solder joint is what mechanically anchors the stack.
  Stock `Connector_PinHeader_2.54mm:PinHeader_2x20_P2.54mm_Vertical` pad
  geometry, rotated 90° and translated so its pads land on that grid (the
  generator measures the resulting pad vectors rather than trusting the
  footprint's anchor convention).

  **One part, not two.** Earlier versions of this board modelled the joint as a
  male header on top plus a female socket on the bottom sharing holes, with 40
  pass-through traces. That is not how it is built. The real part — the one
  LilyGo fit to their own shields — is a single **stacking header**: socket
  barrel below the PCB, pins through and above it. One footprint, one set of 40
  holes, and **no copper between them at all**. The signal path is the header's
  own pin; pin-to-pin identity is a property of the part, not of the board.
  Every pad is an isolated net by design, not by oversight.

- **Silkscreen** carries the whole Raspberry Pi 40-pin function map, because
  the Elite's own header is unlabelled: a per-pin vertical label above each
  column for pins 11–40, a full 40-entry table for all of them, the pin-1 end
  marked, `RJ45 side` by the notch, hole roles, and `T-ETH-Elite -> RPi HAT
  adapter` across the top. The back reads `T-ETH-Elite SIDE`.

  Pins 1–10 get table entries but no per-pin label: their columns sit inside
  the notch's x span, and between the connector body (which covers the board up
  to y = 8.40) and the notch (which starts at y = 10.00) there is no room for a
  legible string. Everything else is labelled at the pin.

### Which pin is pin 1 — derived, not measured

`GEOMETRY.md` fixes the pin *grid* but not the *numbering*, and LilyGo do not
silkscreen it on the Elite (that is part of why this board is worth having).
The labels here assume **pin 1 at the low-x end, on the y = 3.360 row** (odd
pins on the row nearer the board's y = 0 edge, even pins on y = 5.900), on two
grounds:

1. Standard Raspberry Pi: odd pins are the outer row, nearest the board edge.
2. On the Elite, header pins 35 and 37 carry `USB_DN`/`USB_DP` (LilyGo
   schematic sheet 2, J1). Those route to the USB-C receptacle, which is at the
   Elite's **right-hand** edge — so the pin-40 end is at high x, and pin 1 is at
   low x, next to the RJ45. The PoE/5 V input being on the same left side as
   pins 2/4 agrees.

This is an inference, not a measurement. It affects only the silkscreen: the
connection itself is the stacking header's own pin and is correct either way.
If you have a board in hand, check it against the table before trusting a
label.

## Files

| File | What |
|---|---|
| `GEOMETRY.md` | **The source of truth.** Provenance for every number. |
| `make_board.py` | Generator. Emits the `.kicad_pcb` via KiCad 7 `pcbnew` bindings, reads it back and asserts every coordinate, runs DRC, then does all the `kicad-cli` exports. Re-runnable and diffable. |
| `t_eth_elite_hat_adapter.kicad_pcb` / `.kicad_pro` | KiCad 7 board + project |
| `gerbers/t_eth_elite_hat_adapter_gerbers.zip` | Fab-ready: 7 gerber layers, separate PTH/NPTH Excellon drill, drill maps, job file |
| `cpl.csv` | Position file (one line) |
| `bom.csv` | BOM (one line) |
| `preview.svg` / `preview.png` | Front view, so the shape can be seen without opening KiCad |
| `drc.rpt` | DRC report as produced, nothing excluded |

Regenerate everything with `python3 make_board.py`. Geometry is reproducible
to the last internal unit, but the output is not byte-reproducible: KiCad
stamps fresh UUIDs into the `.kicad_pcb` and timestamps into the gerbers on
every run, so a re-run always shows as a diff. Compare the printed coordinate
table, not the files.

Drill files and `cpl.csv` are plotted against the drill/place origin, which the
generator puts on `GEOMETRY.md`'s own origin — so e.g. `NPTH.drl` literally
reads `X3.33Y4.63` and `cpl.csv` reads `8.196, 3.360`. They can be diffed
against `GEOMETRY.md` by eye.

### BOM — one line

A **2×20, 2.54 mm stacking header**: female socket barrel ≈13 mm below the
PCB, pins ≈9 mm above it, one part through one set of 40 holes. The same class
of part LilyGo fit to their own T-ETH-Elite shields. LCSC left blank — the
exact barrel/pin lengths decide the standoff heights, so pick the part first.

### Standoffs

Pick the header first, then the standoffs to match it, not the other way round:

- **Elite → adapter**: set by the chosen header's barrel, ≈13 mm. Must be
  ≥ 15.97 + a little if you want the RJ45 to clear without the notch doing the
  work; with the notch, the barrel height is what it is and the standoffs just
  have to match it. M2.5, four off (H1–H4).
- **Adapter → HAT**: set by that header's above-board pin length. M2.5, four
  off (H1, H2, H5, H6).

## Verification

Every hole centre and all 40 pad centres were read back out of the written
`.kicad_pcb` and compared against `GEOMETRY.md`: **worst error 0.00000 mm**
(tolerance 0.01 mm), 48 of 48 features. `make_board.py` prints the full table
and exits non-zero if any row fails.

### DRC — as reported, nothing excluded

This machine's `kicad-cli` has no `pcb drc` subcommand, so DRC is run through
`pcbnew.WriteDRCReport()` — the same engine — from the generator:

```
** Found 8 DRC violations **
** Found 0 unconnected pads **
** Found 0 Footprint errors **
```

All 8 are the same `lib_footprint_issues` warning, one per hole: *"the current
configuration does not include the library 't_eth_elite_hat_adapter'."* The six
Ø2.75 and two Ø4.0 NPTH holes are generated inline by the script and belong to
no footprint library, so the library-consistency test has nothing to compare
them to. No clearance, courtyard, hole-clearance, silk, edge or connectivity
finding. Nothing is suppressed or excluded; running it yourself reproduces
exactly this.

Two findings were fixed in the generator rather than waved away:

- a real `silk_edge_clearance` hit — pin 9's label crossed the notch edge.
  Per-pin labels now stop where the notch starts.
- J1 had no library link, so the same test could not check it either. It now
  carries its true `Connector_PinHeader_2.54mm:` FPID, and the generator points
  KiCad at its installed library so the test actually runs against the stock
  footprint. It passes.

### No schematic, deliberately

There is no `.kicad_sch`. A board with one connector and no nets has no
meaningful schematic, and inventing one purely to be able to report "ERC clean"
would be worse than having none. The previous version of this board did have
one; it existed only to hold 40 net labels for traces that should never have
been there.

## What is NOT verified — read this before ordering

- **Nothing has been bench-tested.** No adapter, no HAT and no T-ETH-Elite were
  in hand. This is a design, not a working assembly.
- **The HAT's hole pattern is photo-derived.** Measured off the product photo
  scaled by the known 48.26 mm pin-row span, it comes out as a rectangle with
  ratio 0.852 against the Pi spec's 49/58 = 0.845 — consistent with a standard
  Pi pattern, which is why H5/H6 are placed at the Pi's +49.0 mm offset. That
  is the one decision resting on a photo. The listing's "57×75×23 mm" does not
  match the photo and is assumed to be packaging.
- **Pin 1's end is inferred**, not measured — see above.
- **The stacking header is specified by class, not by part number.** Barrel and
  pin lengths vary between vendors and they set both standoff heights.
- **No order was placed.** There is no browser/checkout access here. The
  deliverable is fab-ready files to upload yourself.

Everything the board's *geometry* depends on is measured, not estimated — see
[`GEOMETRY.md`](GEOMETRY.md) for the provenance of each number, including which
of the three LilyGo source files each came from and which set was physically
validated against a real board on a laser-cut plate.

## History

This replaces a board built on KiCad's stock `RaspberryPi-HAT` template: a
65 × 56.5 mm outline with four holes on a 58 × 49 mm **rectangle**, no RJ45
notch, and two coincident footprints joined by 40 pass-through traces. Three
independent things were wrong with it — the Elite's holes are not a rectangle,
an un-notched board fouls the RJ45, and the connection is one stacking header
rather than a header plus a socket plus copper. It was rebuilt from
`GEOMETRY.md` rather than patched.

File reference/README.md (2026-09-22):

# Vendored LilyGo mechanical files, and the script that reads them

Everything dimensional in `../pcb/GEOMETRY.md` — and so the
adapter PCB and the printed tray that depend on it — traces back to the three
files in this folder. They are vendored rather than linked so the numbers stay
reproducible if LilyGo reorganise their repo.

| file | what it is | upstream |
|---|---|---|
| `T-ETH-ELite.dxf` | 2D mechanical drawing of the T-ETH-Elite | `shell/T-ETH-ELite.dxf` |
| `T-ETH-ELite.7z` | 3D model (STL inside) of the T-ETH-Elite — **the exact original** | `shell/3D/T-ETH-ELite.7z` |
| `T-ETH-ELite-LoRa-Shield.7z` | 3D model of LilyGo's own stacking shield — **exact original** | `shell/3D/T-ETH-ELite-LoRa-Shield.7z` |
| `*-view.stl` | the same two models, decimated to ~30% so GitHub renders them in the browser | derived here |

### The `-view.stl` files are for looking at, not for measuring

GitHub's 3D viewer stops at 10 MB and both originals are ~10.5 MB, so the
`-view.stl` pair is decimated (209k → 75k and 211k → 64k triangles, 3.8 MB and
3.2 MB). Decimation eats thin features: the base board's view model comes out
72.500 × 49.192 × **17.703** against the original's 72.500 × 49.352 × **18.822**,
i.e. about 1.1 mm of height is simply gone. Fine for seeing the shape, useless
for dimensions. `measure.py` reads the `.7z` originals and never touches these.

Upstream is [Xinyuan-LilyGO/LilyGO-T-ETH-Series](https://github.com/Xinyuan-LilyGO/LilyGO-T-ETH-Series),
fetched 2026-09-22. The `.7z` archives are kept compressed (≈1.3 MB each);
extracted they are ~10 MB STLs, which is not worth carrying in git.

**Licence: LilyGo's repository states none.** These are the vendor's own
mechanical files for their own product, vendored here for interoperability. If
that is a problem for this repo, delete them — `measure.py --fetch` pulls them
back down and everything still works.

## Reproducing GEOMETRY.md

```bash
pip install --user ezdxf trimesh manifold3d py7zr
python3 measure.py            # uses the files here
python3 measure.py --fetch    # or download them first
```

It prints, straight out of the vendor files:

- the four mounting holes, from the DXF *and* independently from the 3D model,
  and again from LilyGo's own shield — three sources for the same four holes
- the 40-pin grid, recovered by sectioning the header body above its plastic so
  the pins come out as 40 separate closed regions
- the board outline, simplified enough to show the antenna notch on the base
  board and the RJ45 notch on the shield
- every part standing more than 3.5 mm off the PCB — which is where the
  RJ45-vs-header-height problem that justifies the adapter comes from

It does not write anything or edit GEOMETRY.md. Compare by eye; if a number has
drifted, GEOMETRY.md is what needs updating, and every consumer of it
(`../pcb/make_board.py`, `../case/case.py`) re-runs from
constants, not from hand-copied values.

## The one thing it cannot check

The TSN Lab 10Base-T1S HAT has no published CAD. Its 58 × 49 mounting pattern
is inferred from a product photo (see GEOMETRY.md for the method and the error
bars). Nothing in the adapter's fit to the *Elite* depends on that; only the
placement of the adapter's two far holes does.

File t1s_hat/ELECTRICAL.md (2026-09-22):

# T1S HAT — electrical design spec

Our own 10BASE-T1S board for the LilyGO T-ETH-Elite, built around a
**Microchip LAN8651** MAC-PHY. Replaces buying TSN Lab's HAT; same chip family,
same host, our schematic.

Companion to [`../pcb/GEOMETRY.md`](../pcb/GEOMETRY.md), which fixes the
mechanical side and is reused unchanged. This file is the electrical source of
truth: **if the KiCad files disagree with this file, this file is right.**

Every value below is quoted from Microchip DS60001734F (LAN8650/1 data sheet)
or DS60001718D (AN1718, LAN86xx Bus Interface Network reference design). No
value here is inferred or carried over from a similar part.

## Why LAN8651 and not LAN8650

Same pinout except three pins, and those three decide the whole power design:

| pin | LAN8650 | LAN8651 |
|---|---|---|
| 6, 15 | VDDC (+1.8 V core in) | DNC |
| 21 | VDDC (+1.8 V core in) | **CCOMP** |

> "Core LDO Supply Compensation — CCOMP — Internal +1.8 V LDO core
> compensation. This pin requires a 4.7 μF low ESR capacitor to the PCB ground
> plane. This pin is only on the LAN8651." — DS60001734F Table 3-8

**The LAN8651 regulates its own 1.8 V core internally.** The LAN8650 does not:
its reference schematic needs an external 1.8 V LDO plus an SS14 sequencing
diode between the rails. Choosing LAN8651 deletes a regulator, a diode, a rail
and its whole decoupling group, and leaves the board **single-supply 3.3 V**.
TSN Lab's HAT uses LAN8651 too (their device-tree overlay declares
`compatible = "microchip,lan8651"`, and the board silkscreen reads LAN8651 even
though the shop listing says LAN8650).

## Pinout — 32-VQFN 5×5 mm, 0.5 mm pitch, exposed pad = VSS

| # | name | # | name | # | name | # | name |
|---|---|---|---|---|---|---|---|
| 1 | INH | 9 | IRQ_N | 17 | VDDP | 25 | VDDAU |
| 2 | VSS | 10 | SDO | 18 | DIOA0 | 26 | RBIAS |
| 3 | VSS | 11 | CS_N | 19 | DIOA1 | 27 | XTI |
| 4 | TEST | 12 | SCLK | 20 | DIOA2 | 28 | XTO |
| 5 | VSS | 13 | SDI | 21 | **CCOMP** | 29 | VDDA |
| 6 | DNC | 14 | DIOB1 | 22 | DIOA3 | 30 | TRXP |
| 7 | VDDP | 15 | DNC | 23 | DIOA4 | 31 | TRXN |
| 8 | RESET_N | 16 | DIOB0 | 24 | WAKE_OUT | 32 | WAKE_IN |

**Exposed pad must be connected to ground.**

## Mandatory pin handling — quoted, not guessed

| pin | what the data sheet says | so |
|---|---|---|
| TEST (4) | "This pin must be connected to VDDP." | **to 3V3**, not ground. Easy to get backwards. |
| DIOB1 (14) | "reserved for Microchip test use. It is recommended that this pin is connected directly to ground." | to GND |
| DNC (6, 15) | "must be left floating externally" | no connect, no copper stub |
| WAKE_IN (32) | "When not used, this pin should be connected to VSS." | to GND (VDDAU domain) |
| WAKE_OUT (24) | "When not used, this pin should be left unconnected." | NC |
| DIOA0-4, DIOB0 | "When not used, these pins may be connected directly to ground." | see LEDs below; the rest to GND |
| RESET_N (8) | "When not used, this pin must be connected directly to VDDP." | driven from the host **plus** a 10 k pull-up to 3V3, so a floating GPIO during ESP32 boot cannot hold the PHY in reset |
| RBIAS (26) | "requires connection of a 12.4 kΩ resistor to ground… within ±1% across the entire expected operating temperature range" | **12.4 kΩ 1 %**, no substitutions |

## Power — single 3.3 V rail

3V3 comes from the 40-pin header (pins 1 and 17). No other rail on the board.

| net | pins |
|---|---|
| VDDP | 7, 17 |
| VDDA | 29 |
| VDDAU | 25 (must stay powered in sleep — here it is simply always on) |

Decoupling, per the data sheet's own layout rule — *"Place one 0.01 µF and one
0.1 µF at each power pin. The 0.01 µF must be closest to the pin."*:

- **each** of VDDP 7, VDDP 17, VDDA 29, VDDAU 25 → 0.1 µF + 0.01 µF
- one 10 µF bulk near the device, on the supply side
- **CCOMP (21) → 4.7 µF low-ESR** to ground. Required, not optional. 0.1 µF and
  0.01 µF alongside are "useful but not required" — include the 0.1 µF.
- Ideally two vias per decoupling cap to the plane, and caps must not share vias.

Optional, footprint-only: ferrite beads (~300 Ω @ 100 MHz, e.g. Würth
742792640, DC rating ≥2× the pin current) to island VDDA / VDDAU / VDDP. The
data sheet recommends carrying the option through prototype. Populate 0 Ω.

## Clock

25.0 MHz crystal, fundamental, parallel resonant, across XTI (27) / XTO (28),
load caps **C1 = C2 = 18 pF** (data sheet allows 10–22 pF).

> "external series resistors should not be used… The device contains an internal
> ~1 MΩ resistance in parallel with the crystal amplifier… therefore an external
> resistance between XTO and XTI should not be used."

So: no series resistor, no feedback resistor. Oscillator margin should be >10
and at least 5 — a crystal with low ESR and the right CL matters here.

## Host interface — matches TSN Lab's device-tree overlay on purpose

Their overlay (`lan8650-overlay-rpi4.dts`) declares `spi0`, `reg = <0>` (CE0),
`interrupts = <23 …>`. Wiring to the same header pins means their SDK and the
mainline `microchip,lan8651` driver both work unmodified if this board is ever
put on a Pi, and costs nothing on the ESP32 side.

| LAN8651 | header pin | RPi name | ESP32-S3 on the Elite |
|---|---|---|---|
| SDI (13) | 19 | GPIO10 / SPI0 MOSI | per LilyGo's mapping |
| SDO (10) | 21 | GPIO9 / SPI0 MISO | |
| SCLK (12) | 23 | GPIO11 / SPI0 SCLK | |
| CS_N (11) | 24 | GPIO8 / SPI0 CE0 | 10 k pull-up to 3V3 |
| IRQ_N (9) | 16 | GPIO23 | 10 k pull-up to 3V3 |
| RESET_N (8) | 15 | GPIO22 | 10 k pull-up to 3V3 |

SPI clock up to 25 MHz. Protocol is OPEN Alliance TC6.

We deliberately do **not** copy TSN Lab's FXL6408 I²C GPIO expander (their
GPIO24 interrupt) or their rotary node-ID switch: the PLCA node ID is a
register write, so it belongs in firmware, and dropping the expander removes a
part, an I²C bus and an interrupt line.

## Bus Interface Network — TRXP (30) / TRXN (31) to the cable

Order from the chip outward, per AN1718:

```
TRXP/TRXN ─ CMC(L1) ─ C1/C2 100nF ─ [R1/R2 termination] ─ [ESD] ─ CN1
```

| ref | value | note |
|---|---|---|
| L1 | common-mode choke, 130 µH @ 100 kHz — TDK ACT1210D-131-2P-TL00 (or ACT1210E-241 / Murata DLW32MH241MX2) | **always populated** |
| C1, C2 | 0.1 µF, 100 V, 0805 | DC block / galvanic isolation. **Always populated, on every node.** |
| R1, R2 | **49.9 Ω 1 % 1 W 1206** for an END-OF-BUS node<br>**1.5 kΩ 1 % 1206** for an interior DROP node | footprints fitted, **DNP by default** — stuff per where this node sits on the bus |
| R3 | 100 kΩ 5 % 0805 + C3 | common-mode termination (drop node), per AN1718's drop-node topology |
| MOV1/2 | TDK AVRH10C221KT1R5YA8 or Panasonic EZA-EG3W11AV | ESD, optional, footprint by the connector |
| CN1 | 4-pin 3.81 mm pluggable terminal block | P_in/N_in + P_out/N_out, the two P's and the two N's shorted on board so the node taps a daisy chain |

**No pin header on the bus.** AN1718 wants ESD and termination in-line with
stubs minimised; a jumper header on T1S is a stub. Termination is selected by
which resistors get stuffed, marked on silkscreen, not by a removable jumper.

## Status LEDs

Two, on DIOA0 (18) and DIOA1 (19) — configurable outputs in the VDDP domain, so
1 kΩ series to 3V3. Firmware maps them to PLCA status / activity. Remaining
DIOA2/3/4 and DIOB0 go to ground.

## Board rules

- **2-layer, 1.6 mm.** AN1718 asks for TRXP/TRXN as length-matched 50 Ω
  single-ended, which would need ~2.9 mm traces on 2-layer 1.6 mm FR4 and
  ~0.35 mm on a 4-layer stack. The width figure is right; the conclusion that
  this board needs four layers is not. 10BASE-T1S runs at 12.5 MBd with
  deliberately slow, EMC-shaped edges, and the run from the QFN to the bus
  connector here is ~20-25 mm — electrically short at those edge rates. The
  50 Ω line is a "do this and you are safe" recommendation, not a threshold
  this design crosses. Four layers stays the fallback if EMC measurement later
  asks for it; it is not a correctness issue now.
- **All signals on F.Cu; B.Cu is an uninterrupted ground pour.** This is the
  discipline that buys back what the fourth layer would have given. The board
  carries only SPI×4, IRQ, RESET, 3V3 and GND, so there is no reason for a
  single bottom-side trace to slot the reference plane under the T1S pair.
- **TRXP/TRXN short, length-matched, symmetric, no vias.** Let this drive
  placement: the LAN8651 goes near the bus connector, ahead of tidiness.
- **All-layer void under the common-mode choke**, per AN1718, to stop coupling
  from its core.
- ESD parts and coupling caps close to the connector; minimise stubs on the bus.
- Exposed pad stitched to the ground plane with a via array.
- **Antenna keepout:** the Elite's ESP32-S3-WROOM antenna sits under this board
  at x 58…66.22, y 22…44 (its own PCB is cut away at x 59.84…66.19,
  y 23.93…42.22). A ground plane above a PCB antenna detunes it, so **no copper
  on any layer** in that window. On a 2-layer board with a poured bottom plane
  this is the single easiest thing to get wrong.

## Mechanical — inherited, with one deliberate departure

From [`../pcb/GEOMETRY.md`](../pcb/GEOMETRY.md), unchanged:

- outline 66.22 × 49.19, R3 corners
- four asymmetric mounting holes (3.33, 4.63) (61.33, 4.63) (2.98, 46.23)
  (63.23, 46.20) — 58.00 apart at the bottom, 60.25 at the top, self-keying
- 2×20 header grid, x = 8.196 + 2.54·k (k = 0…19), y = 3.360 and 5.900

**Departure: no RJ45 notch. The outline is a plain rectangle.** GEOMETRY.md's
notch exists for a board sitting ~13 mm up, which would foul the Elite's
15.97 mm RJ45. This board is instead lifted clear of the jack on a taller
riser, so nothing has to be cut away — and that matters more than convenience
here, because the notch was the largest interruption in the bottom-side ground
pour, right where the T1S pair and its choke want a clean reference.

### The riser is two-stage, and this is easy to get wrong

The Elite's header pins are only **9.30 mm** tall. A single tall stacking
header does *not* work: its contacts sit near the top of the barrel, so with a
~17 mm barrel the Elite's pins reach barely halfway and never touch. What
works is two stages — a 2×20 stacking riser onto the Elite's pins, presenting
longer pins, then this board's socket onto those. Put that in the BOM notes,
not just here.

Resulting height above the Elite PCB: **≈18-20 mm**, set by the riser. Nothing
in the design may depend on an exact figure.

The Elite carries an on-board PoE front end — RJ45 `HY931147C` tapping
POWER+/− into an **SDaPo DP9900M-5V** PD module (5 V, 9 W @ 70 °C), with a
polyfuse, an SMAJ58A TVS and 4.7 nF/2 kV isolation caps. That module is **not
in LilyGo's 3D model** (it does not appear among the parts over 3.5 mm) and
SDaPo's datasheet carries no dimensioned drawing, so CAD cannot settle its
height. Reported from the physical board: **it stands about level with the
RJ45**, so the RJ45's measured 15.97 mm remains the height to clear and the
riser covers both. Source is direct observation of the real hardware, not a
document — if a future board revision changes the PD module, re-check it.

### Bottom side is usable

At ~18-20 mm the underside of this board has 14+ mm of clearance everywhere
except over the RJ45 footprint (x −5.18…16.42, y 10.50…28.90), where it is
much less. Prefer the bottom for anything bulky. A later radar variant will
want that space.

## Not decided here

- Radar variant (A121 / XM125) — a derivative of this board, specified
  separately once this one links.
- PLCA node count, node IDs, coordinator election: firmware, not hardware.

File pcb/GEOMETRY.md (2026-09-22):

# Verified geometry — the single source of truth for this board

Every number below was measured from a primary source and cross-checked against
at least one independent one. Nothing here is estimated, rounded from a photo,
or carried over from the Raspberry Pi HAT spec by assumption. **If the KiCad
files and this file ever disagree, this file is right and the board is wrong.**

Frame used throughout: **T-ETH-Elite top view, origin = its PCB bottom-left
corner, +x right, +y up.** All units mm.

## Sources

| tag | what | where |
|---|---|---|
| `DXF` | LilyGo 2D mechanical DXF | `shell/T-ETH-ELite.dxf`, github.com/Xinyuan-LilyGO/LilyGO-T-ETH-Series |
| `CAD` | LilyGo 3D model of the base board | `shell/3D/T-ETH-ELite.7z` → `T-ETH-ELite.stl`, same repo |
| `SHLD` | LilyGo 3D model of their own LoRa shield | `shell/3D/T-ETH-ELite-LoRa-Shield.7z`, same repo |
| `RIG` | `/home/kim/stl-model/acrylic-frame/make_plates.py` — the same hole set, **physically validated**: a real board was offered up to a laser-cut plate and sat centred on its holes (see that repo's `CUTTING.md`) |

## T-ETH-Elite base board

| item | value | source |
|---|---|---|
| PCB outline | 66.191 × 49.192, R3 corners | `CAD` slab; `DXF` agrees |
| antenna keepout notch (right edge) | x 59.84…66.19, y 23.93…42.22 | `CAD` outline |
| PCB thickness | 1.575 (≈1.6) | `CAD` |

### Mounting holes — asymmetric, NOT a rectangle

| # | `DXF` | `CAD` | `SHLD` | **use this** (`RIG`, physically validated) |
|---|---|---|---|---|
| bottom-left | (3.327, 4.628) | (3.339, 4.630) | (3.333, 4.636) | **(3.33, 4.63)** |
| bottom-right | (61.367, 4.638) | (61.339, 4.630) | (61.433, 4.636) | **(61.33, 4.63)** |
| top-left | (2.987, 46.288) | (2.991, 46.228) | (3.004, 46.228) | **(2.98, 46.23)** |
| top-right | (63.227, 46.198) | (63.241, 46.198) | (63.254, 46.198) | **(63.23, 46.20)** |

Bottom pair spacing **58.00**, top pair **60.25** — the asymmetry is real design,
not a CAD slip; three independent files agree to <0.1. PCB hole Ø2.500 on the
board itself; M2.5 hardware.

A useful consequence: **the pattern is self-keying.** 58.00 ≠ 60.25 means this
adapter physically cannot be bolted on rotated 180°.

### 40-pin GPIO header

| item | value | source |
|---|---|---|
| pin grid | 20 cols × 2 rows, 2.54 pitch | `CAD`, sectioned above the plastic |
| column x | 8.196 + 2.54·k, k = 0…19 → 8.196 … 56.456 | `CAD` |
| row y | **3.360** and **5.900** | `CAD` |
| plastic body | x 6.926…57.726 (=50.800), y 0.860…8.399 | `CAD` |
| pin tip height | z = 10.10, i.e. **9.30 above the PCB** | `CAD` |

Internal consistency check that ties the two datasets together: the pin field is
centred at x 32.326 against the bottom hole pair's centre 32.33, and the rows sit
at 4.63 ± 1.27 — exactly straddling the bottom holes' y. That is the Raspberry Pi
header-to-hole relationship, reproduced by LilyGo.

### Component heights above the PCB — what a stacked board must clear

Heights below are LilyGo CAD z, in which the PCB's **top face is at 0.80**
(the 1.575 slab is centred on z=0). Subtract 0.80 for height above the PCB
surface. The comparison that matters is a difference, so it holds in either
frame.

| part | top (CAD z) | = above PCB | footprint |
|---|---|---|---|
| **RJ45 (with magnetics)** | **15.97** | **15.17** | x −5.18…16.42 (hangs 5.18 off the left edge), y 10.50…28.90 |
| 40-pin header pins | 10.10 | 9.30 | x 6.93…57.73, y 0.86…8.40 |
| two parts at the far edge (BOOT/RST) | 4.00 | 3.20 | x 41.48…45.98 and 52.10…56.60, y 45.85…49.35 |
| ESP32-S3-WROOM-1 | 3.90 | 3.10 | x 40.47…65.97, y 24.07…42.08 |

**The RJ45 is 5.87 mm taller than the header pins.** Anything that plugs onto
that header and spans the left half of the board fouls it unless it is notched
**or** lifted clear of 15.97 altogether.

Stated precisely, because an earlier draft of this file overstated it: a tall
enough stacking header alone would lift a HAT above the RJ45 with no adapter at
all. What that does *not* give you is anywhere to put the HAT's far mounting
pair, which lands at y = 53.63, past the Elite's own 49.19 edge — so the HAT
would hang off two screws at the connector end. On a board carrying a
lever-actuated terminal block that is the difference between a fixture and a
wobble. The notch, the far holes and the BOOT/RST access are what this board
adds; only the last two are things a header cannot do.

## LilyGo's own LoRa shield — the reference design for stacking on this board

| item | value |
|---|---|
| outline | same 66.22 × 49.19, R3 |
| **RJ45 notch** | x 0…16.87, y 11.25…28.45 (cut into the left edge) |
| mounting holes | the same 4 asymmetric holes, within 0.1 of the base board |
| connector | one 2×20 **stacking header**: socket barrel ~13.0 below the shield PCB, pins reaching 9.30 above it — one part, one set of 40 holes |

So LilyGo stack their shields at ~13 mm above the base PCB and clear the RJ45
with a notch. This adapter does the same thing.

## The TSN Lab 10Base-T1S HAT (the board this adapter exists to carry)

Silkscreen on the product photo reads **`10BASE-T1S HAT / LAN8651 / For RPi /
TSNlab+Ethercrafts`** — note **LAN8651**, not the LAN8650 the devicemart listing
states.

Measured off the product photo, scaled by the known 48.26 mm pin-row span:

| item | value | confidence |
|---|---|---|
| mounting holes | a **rectangle**, ratio 0.852 vs the Pi spec's 49/58 = 0.845 | good — it is a standard Pi 58 × 49 pattern |
| board | ≈63 × 55, i.e. a normal-size HAT | photo-derived, ±2 |
| edge inset of holes | ≈3.5 | photo-derived |

Photo-derived numbers are **not** used for anything this board's correctness
depends on. They are used only to justify one decision: that placing the two far
holes on the Pi spec's 49 mm offset is the right call. The listing's "57×75×23"
does not match the photo and is assumed to be packaging.

## Therefore — this adapter

Outline 0…66.22 × 0…**57.20**, R3 corners. Same width as the base board;
extended +8.0 in y past it so it can carry the HAT's far mounting holes, which
land beyond the base board's own edge.

**RJ45 notch: x 0…17.40, y 10.00…29.40** — deliberately ~0.5 larger all round
than the RJ45's measured envelope, rather than a copy of LilyGo's slightly
tighter 16.87/11.25/28.45. The notch region is empty board on this design, so
the extra clearance costs nothing.

### Holes — 6, all Ø2.75 (M2.5 free fit)

| ref | position | serves |
|---|---|---|
| H1 | (3.33, 4.63) | T-ETH-Elite bottom-left **and** HAT near-left |
| H2 | (61.33, 4.63) | T-ETH-Elite bottom-right **and** HAT near-right |
| H3 | (2.98, 46.23) | T-ETH-Elite top-left |
| H4 | (63.23, 46.20) | T-ETH-Elite top-right |
| H5 | (3.33, 53.63) | HAT far-left |
| H6 | (61.33, 53.63) | HAT far-right |

H1/H2 are shared on purpose. Deriving the Pi near-hole positions in this frame
from the header (centre 32.326 ± 29.0, y = the header centre 4.63) gives
(3.326, 4.63) and (61.326, 4.63) — the T-ETH-Elite's own bottom holes to within
**0.005 mm**. They are the same holes; one pair is drilled, not two.

H5/H6 are H1/H2 offset by the Pi spec's +49.0 in y.

### Connector

One 2×20 THT stacking header, pins on the grid above: x = 8.196 + 2.54·k
(k = 0…19), y = 3.360 and 5.900. Plated through-holes with annular rings both
sides — the solder joint is what mechanically anchors the stack.

No traces. The signal path is the stacking header's own pin, straight through
from the socket below to the exposed pin above; the board contributes nothing
electrical and pin-to-pin identity is guaranteed by the part, not by copper.
Every pad is an isolated net by design.

### Stack-up that results

```
   TSN Lab 10Base-T1S HAT (LAN8651)
        ↑ plugs onto the pins protruding above the adapter
   ── this adapter ──                      ≈13 above the Elite PCB
        ↑ stacking-header socket swallows the Elite's 9.30 pins
        ↑ RJ45 (15.97) passes up through the notch
   LilyGO T-ETH-Elite (ESP32-S3)
```

Standoffs: Elite → adapter ≈13 (set by the chosen stacking header's barrel);
adapter → HAT set by that header's above-board pin length. Both are properties
of the header part, so pick the standoffs after picking the header, not before.

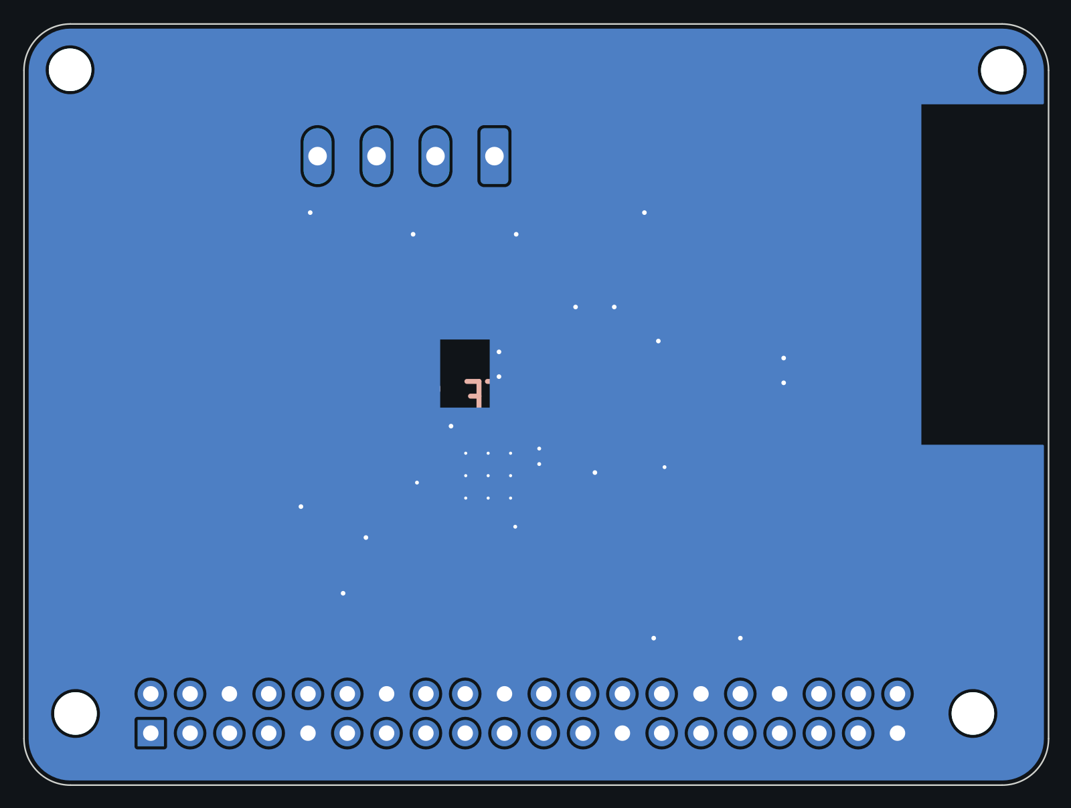
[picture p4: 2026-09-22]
t1s_hat/preview-back.png

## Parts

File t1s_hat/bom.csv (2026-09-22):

Comment | Designator | Footprint | Quantity | Populate | Description | LCSC
100nF/100V | C1 | Capacitor_SMD:C_0805_2012Metric | 1 | fit | AC coupling / galvanic isolation, bus P. ALWAYS FITTED (AN1718)
10nF | C10 | Capacitor_SMD:C_0603_1608Metric | 1 | fit | VDDP (pin 17) decoupling, 0.01 uF - closest to the pin
100nF | C11 | Capacitor_SMD:C_0603_1608Metric | 1 | fit | VDDA (pin 29) decoupling, 0.1 uF
10nF | C12 | Capacitor_SMD:C_0603_1608Metric | 1 | fit | VDDA (pin 29) decoupling, 0.01 uF - closest to the pin
100nF | C13 | Capacitor_SMD:C_0603_1608Metric | 1 | fit | VDDAU (pin 25) decoupling, 0.1 uF
10nF | C14 | Capacitor_SMD:C_0603_1608Metric | 1 | fit | VDDAU (pin 25) decoupling, 0.01 uF - closest to the pin
18pF | C15 | Capacitor_SMD:C_0603_1608Metric | 1 | fit | Crystal load capacitor C1 (data sheet: C1 = C2 = 18 pF)
18pF | C16 | Capacitor_SMD:C_0603_1608Metric | 1 | fit | Crystal load capacitor C2 (data sheet: C1 = C2 = 18 pF)
100nF/100V | C2 | Capacitor_SMD:C_0805_2012Metric | 1 | fit | AC coupling / galvanic isolation, bus N. ALWAYS FITTED (AN1718)
100nF/100V | C3 | Capacitor_SMD:C_0805_2012Metric | 1 | fit | Common-mode termination, centre tap to ground (AN1718 C3)
4.7uF low-ESR | C4 | Capacitor_SMD:C_0805_2012Metric | 1 | fit | CCOMP: internal +1.8 V core LDO compensation. REQUIRED, low ESR, to the ground plane (LAN8651 only).
100nF | C5 | Capacitor_SMD:C_0603_1608Metric | 1 | fit | CCOMP support capacitor (data sheet: useful, not required)
10uF | C6 | Capacitor_SMD:C_0805_2012Metric | 1 | fit | Bulk decoupling on the 3.3 V supply side
100nF | C7 | Capacitor_SMD:C_0603_1608Metric | 1 | fit | VDDP (pin 7) decoupling, 0.1 uF
10nF | C8 | Capacitor_SMD:C_0603_1608Metric | 1 | fit | VDDP (pin 7) decoupling, 0.01 uF - closest to the pin
100nF | C9 | Capacitor_SMD:C_0603_1608Metric | 1 | fit | VDDP (pin 17) decoupling, 0.1 uF
T1S BUS P N N P | CN1 | Connector_Phoenix_MC:PhoenixContact_MC_1,5_4-G-3.81_1x04_P3.81mm_Horizontal | 1 | fit | MDI connector, 4-pin 3.81 mm pluggable terminal block. Pins 1..4 = P N N P; the two P and the two N are shorted on board so the node taps a daisy chain.
GRN | D1 | LED_SMD:LED_0603_1608Metric | 1 | fit | Status LED 0 on DIOA0 - firmware maps it (e.g. PLCA status)
YEL | D2 | LED_SMD:LED_0603_1608Metric | 1 | fit | Status LED 1 on DIOA1 - firmware maps it (e.g. activity)
0R (FB opt.) | FB1 | Inductor_SMD:L_0603_1608Metric | 1 | fit | VDDA supply island option: 0 ohm fitted; may be replaced by a ~300 ohm @ 100 MHz bead (e.g. Wuerth 742792640).
0R (FB opt.) | FB2 | Inductor_SMD:L_0603_1608Metric | 1 | fit | VDDAU supply island option: 0 ohm fitted.
0R (FB opt.) | FB3 | Inductor_SMD:L_0603_1608Metric | 1 | fit | VDDP supply island option: 0 ohm fitted.
2x20 socket (riser stack) | J1 | Connector_PinHeader_2.54mm:PinHeader_2x20_P2.54mm_Vertical | 1 | fit | 2x20 2.54 mm THT socket; mates with the riser that plugs onto the T-ETH-Elite's own 9.30 mm header pins
0R jumper | JP1 | Resistor_SMD:R_0603_1608Metric | 1 | fit | 0 ohm link, VDDP pin-7 island to VDDP pin-17 island. The 2-layer crossover for +3V3, which passes between its pads. FITTED - the board does not work without it.
200uH @ 100kHz CMC | L1 | t1s_hat:L_CommonMode_TDK_ACT1210_3225 | 1 | fit | Common-mode choke, 2-line, 200 uH @ 100 kHz, EIA 1210 (3.2x2.5 mm), AEC-Q200 - TDK ACT1210L-201-2P-TL00 (AN1718 L1). ALWAYS FITTED. | C131444
22V 1.5pF ESD (DNP) [DNP] | MOV1 | t1s_hat:Varistor_TDK_AVRH10_1005 | 1 | DNP | ESD element on bus P, at the connector (AN1718 MOV1) - TDK AVRH10C221KT1R5YA8 chip varistor, 1005 [0402], 1.5 pF. Optional. | C2157827
22V 1.5pF ESD (DNP) [DNP] | MOV2 | t1s_hat:Varistor_TDK_AVRH10_1005 | 1 | DNP | ESD element on bus N, at the connector (AN1718 MOV2) - TDK AVRH10C221KT1R5YA8 chip varistor, 1005 [0402], 1.5 pF. Optional. | C2157827
49R9 1% 1W (DNP) [DNP] | R1 | Resistor_SMD:R_1206_3216Metric | 1 | DNP | Bus termination, P leg. 49R9 1% 1W for an END node, 1K5 1% for a DROP node. Shipped unstuffed - see README.
49R9 1% 1W (DNP) [DNP] | R2 | Resistor_SMD:R_1206_3216Metric | 1 | DNP | Bus termination, N leg. 49R9 1% 1W for an END node, 1K5 1% for a DROP node. Shipped unstuffed - see README.
100k 5% | R3 | Resistor_SMD:R_0805_2012Metric | 1 | fit | Common-mode termination, centre tap to ground (AN1718 R3)
10k | R4 | Resistor_SMD:R_0603_1608Metric | 1 | fit | RESET_N pull-up: a floating host GPIO during ESP32 boot must not hold the PHY in reset
10k | R5 | Resistor_SMD:R_0603_1608Metric | 1 | fit | SPI CS_N pull-up; also the F.Cu crossover for SPI_MISO, which passes between its pads
10k | R6 | Resistor_SMD:R_0603_1608Metric | 1 | fit | IRQ_N pull-up (open-drain capable interrupt output)
12k4 1% | R7 | Resistor_SMD:R_0603_1608Metric | 1 | fit | RBIAS. 12.4 kohm 1% over the whole operating temperature range - no substitutions (data sheet).
1k | R8 | Resistor_SMD:R_0603_1608Metric | 1 | fit | LED0 series resistor to 3V3 (DIOA0 sinks)
1k | R9 | Resistor_SMD:R_0603_1608Metric | 1 | fit | LED1 series resistor to 3V3 (DIOA1 sinks)
LAN8651 | U1 | Package_DFN_QFN:TQFN-32-1EP_5x5mm_P0.5mm_EP3.4x3.4mm_ThermalVias | 1 | fit | Microchip LAN8651 10BASE-T1S MAC-PHY, OPEN Alliance TC6 SPI, 32-VQFN 5x5 (internal 1.8 V core LDO -> single 3.3 V rail)
25.000MHz | Y1 | Crystal:Crystal_SMD_3215-2Pin_3.2x1.5mm | 1 | fit | 25.000 MHz fundamental parallel-resonant crystal, CL 18 pF, low ESR. No series or feedback resistor (data sheet).

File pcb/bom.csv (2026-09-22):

Comment | Designator | Footprint | Quantity | Description | LCSC
2x20 2.54mm stacking header | J1 | Connector_PinHeader_2.54mm:PinHeader_2x20_P2.54mm_Vertical | 1 | 40-way (2x20) 2.54 mm stacking header: female socket barrel ~13 mm below the PCB, pins ~9 mm above it, one part through one set of 40 holes. Same class of part LilyGO fit to their own T-ETH-Elite shields.

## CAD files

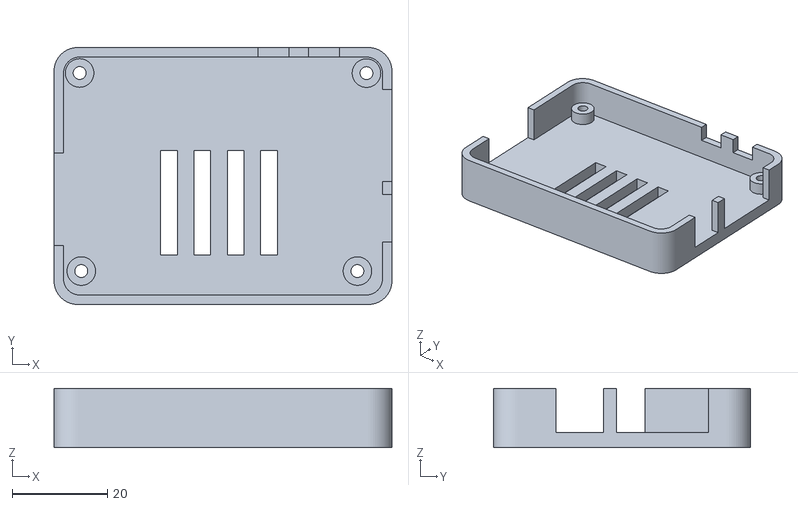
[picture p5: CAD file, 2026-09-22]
case/case_bottom.stl
71.0 x 54.0 x 12.4

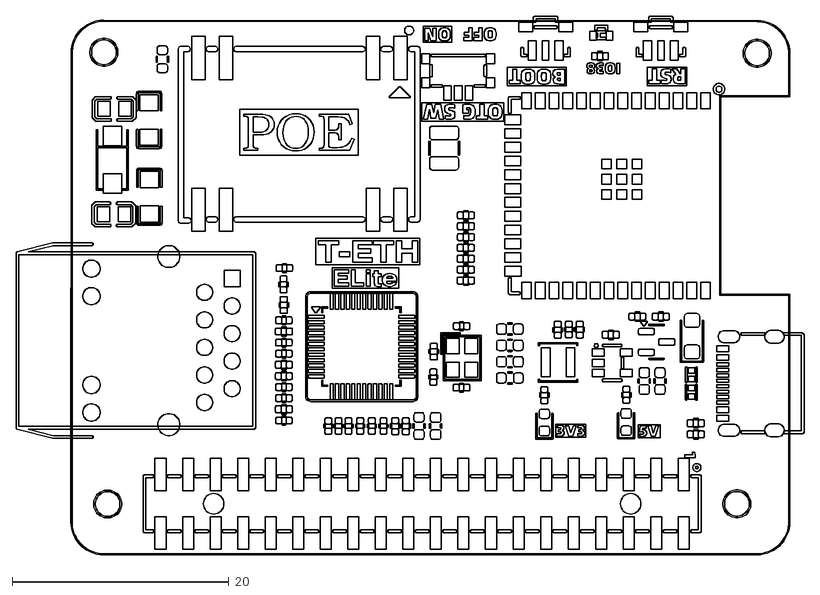
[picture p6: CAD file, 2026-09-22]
reference/T-ETH-ELite.dxf
72.7 x 49.7

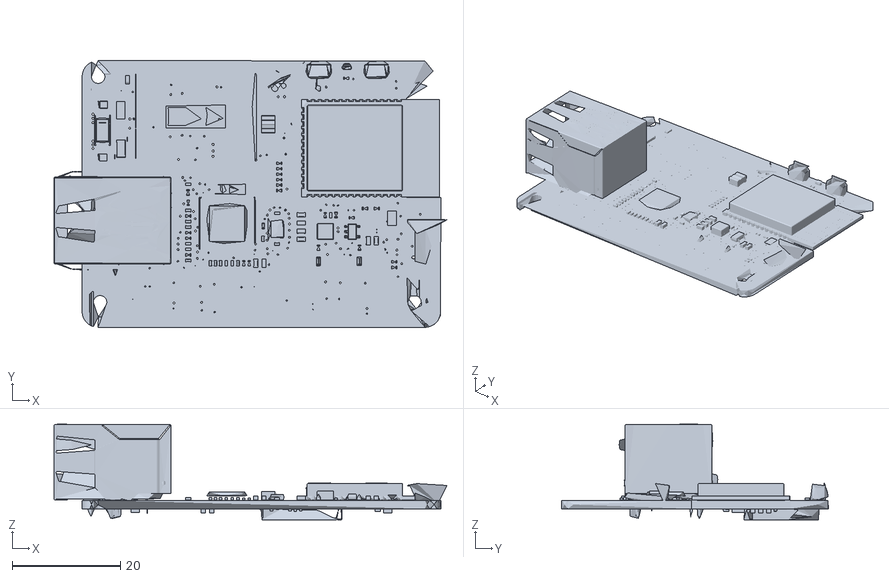
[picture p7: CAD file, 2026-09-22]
reference/T-ETH-ELite-view.stl
72.5 x 49.2 x 17.7

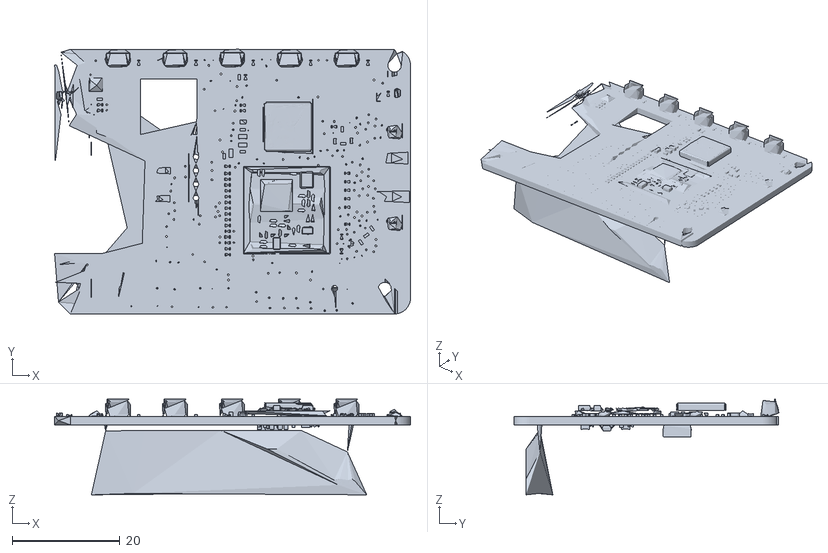
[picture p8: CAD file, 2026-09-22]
reference/T-ETH-ELite-LoRa-Shield-view.stl
66.2 x 49.2 x 17.8

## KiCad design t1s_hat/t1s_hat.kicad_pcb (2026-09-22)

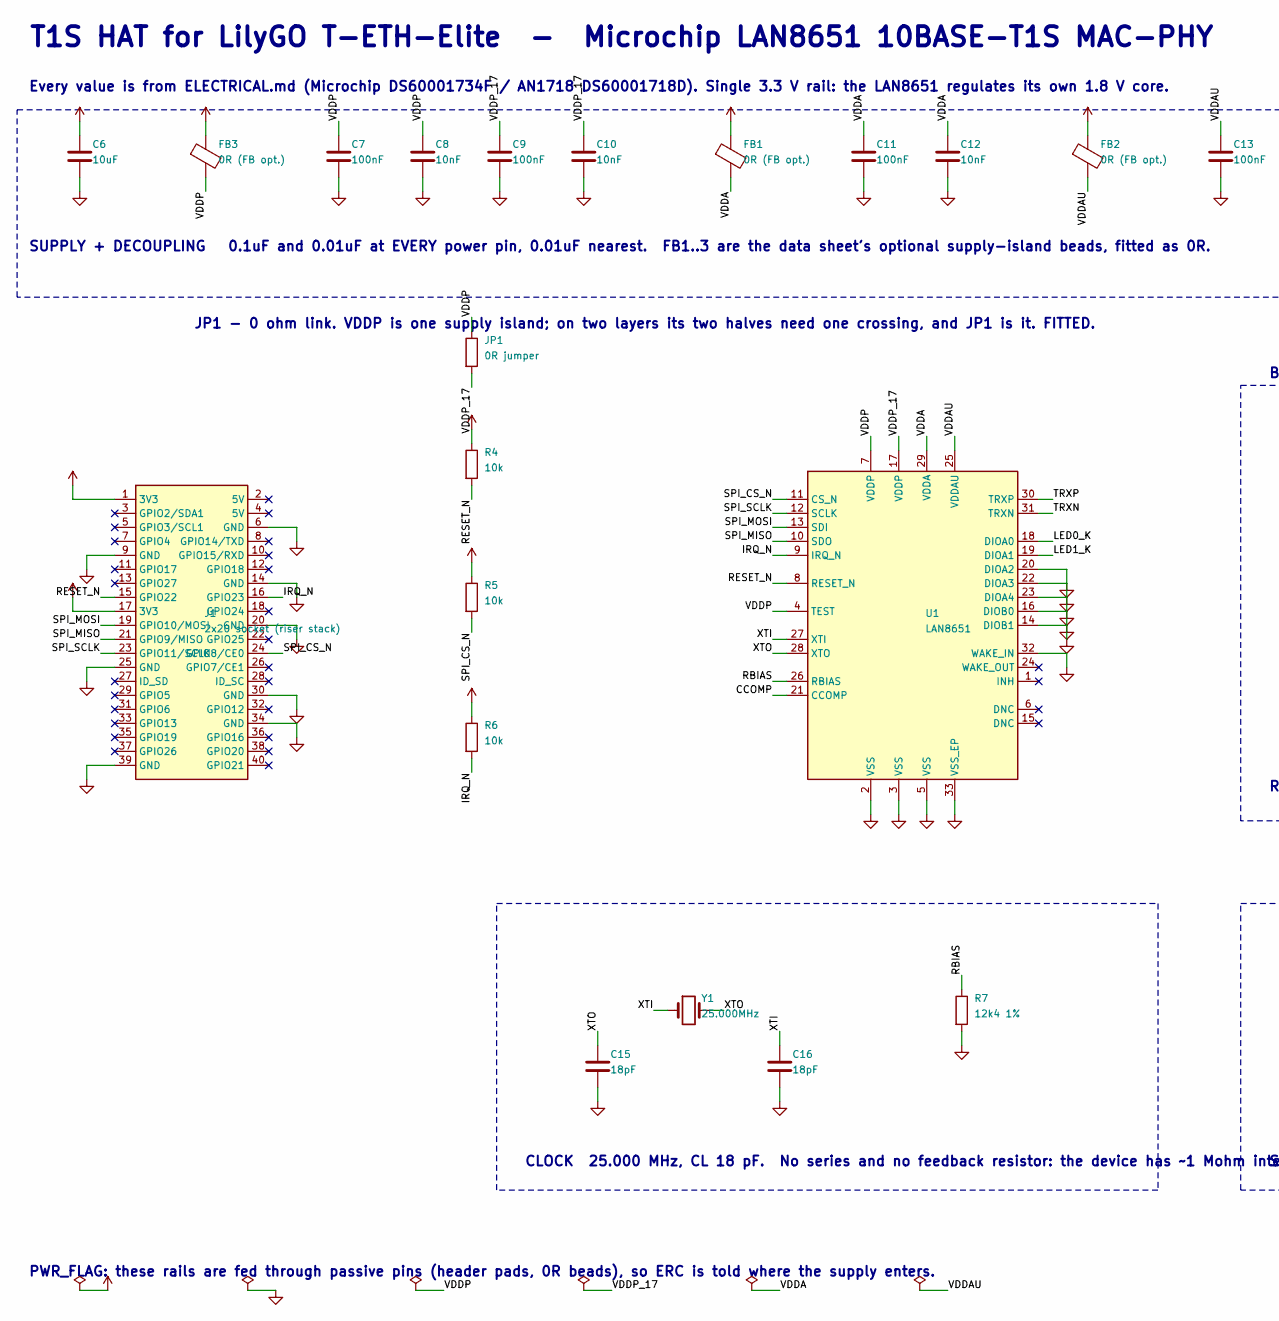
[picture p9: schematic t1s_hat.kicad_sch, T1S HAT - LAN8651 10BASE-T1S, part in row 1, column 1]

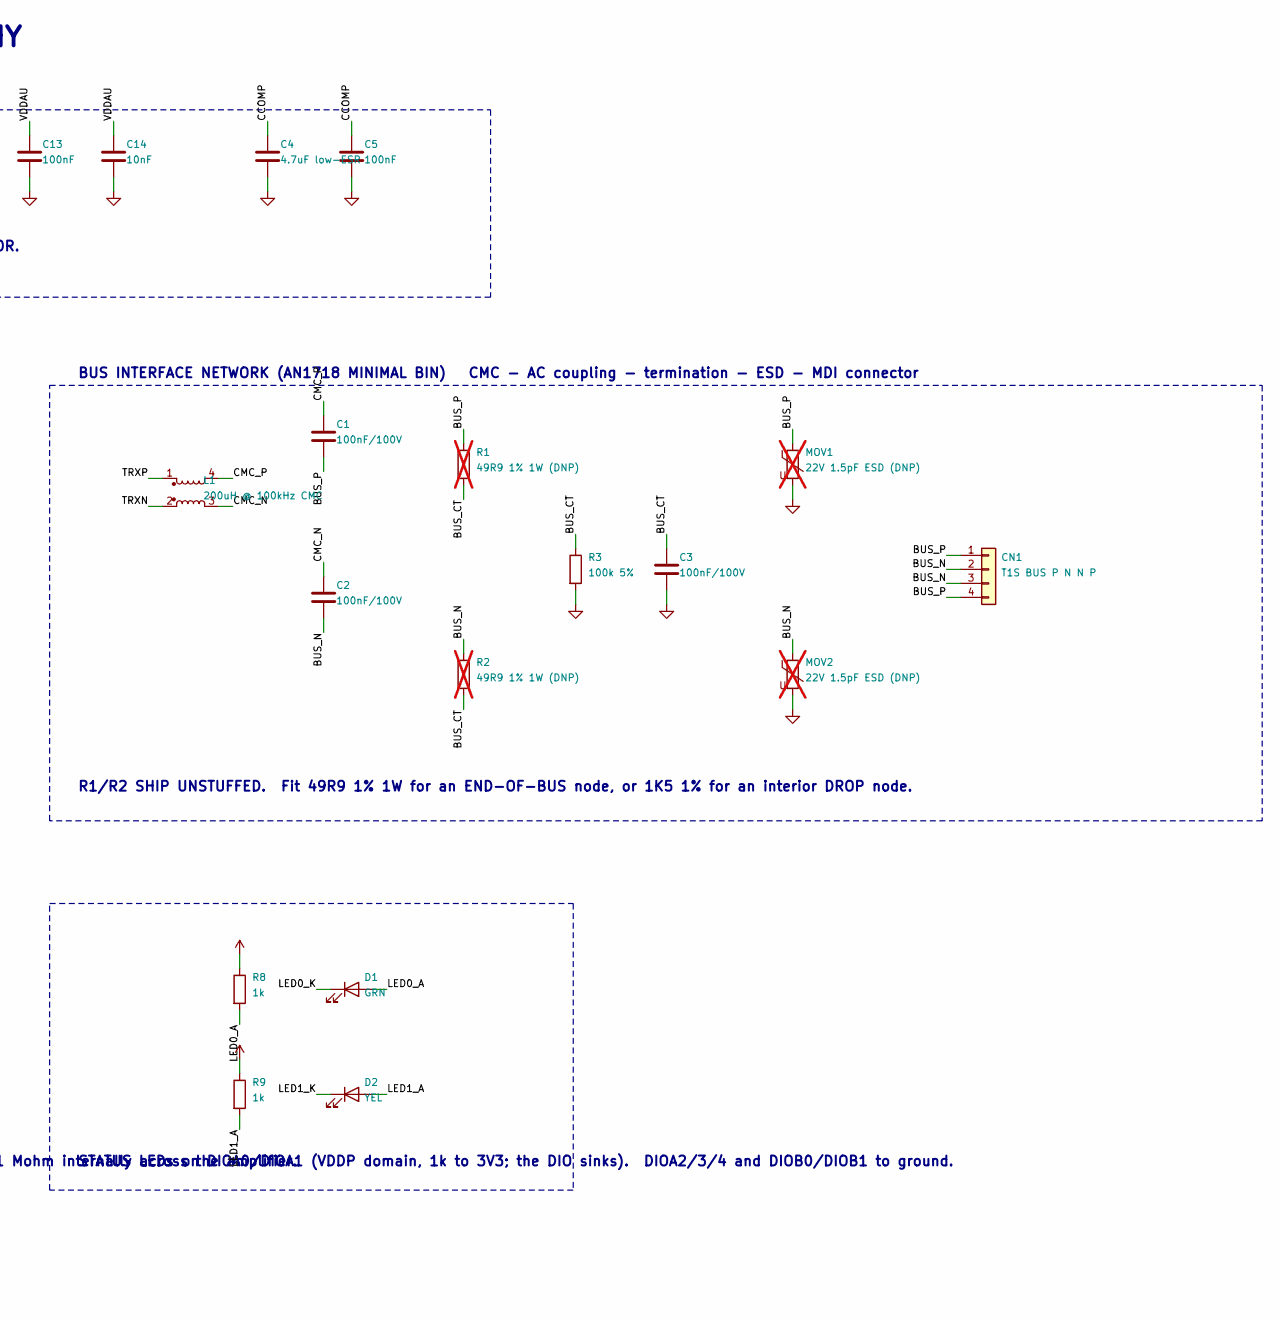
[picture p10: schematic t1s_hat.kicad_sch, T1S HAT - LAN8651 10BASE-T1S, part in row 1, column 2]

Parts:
C1, C2, C3: 100nF/100V; C_0805_2012Metric
C4: 4.7uF low-ESR; C_0805_2012Metric
C5, C7, C9, C11, C13: 100nF; C_0603_1608Metric
C6: 10uF; C_0805_2012Metric
C8, C10, C12, C14: 10nF; C_0603_1608Metric
C15, C16: 18pF; C_0603_1608Metric
CN1: T1S BUS P N N P; PhoenixContact_MC_1,5_4-G-3.81_1x04_P3.81mm_Horizontal
D1: GRN; LED_0603_1608Metric
D2: YEL; LED_0603_1608Metric
FB1, FB2, FB3: 0R (FB opt.); L_0603_1608Metric
J1: 2x20 socket (riser stack); PinHeader_2x20_P2.54mm_Vertical
JP1: 0R jumper; R_0603_1608Metric
L1: 200uH @ 100kHz CMC; L_CommonMode_TDK_ACT1210_3225; LCSC C131444
MOV1, MOV2: 22V 1.5pF ESD (DNP); Varistor_TDK_AVRH10_1005; LCSC C2157827; not fitted
R1, R2: 49R9 1% 1W (DNP); R_1206_3216Metric; not fitted
R3: 100k 5%; R_0805_2012Metric
R4, R5, R6: 10k; R_0603_1608Metric
R7: 12k4 1%; R_0603_1608Metric
R8, R9: 1k; R_0603_1608Metric
U1: LAN8651; TQFN-32-1EP_5x5mm_P0.5mm_EP3.4x3.4mm_ThermalVias
Y1: 25.000MHz; Crystal_SMD_3215-2Pin_3.2x1.5mm

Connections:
+3V3: C6.1, FB1.1, FB2.1, FB3.1, J1.1 (3V3), J1.17 (3V3), R4.1, R5.1, R6.1, R8.1, R9.1
BUS_CT: C3.1, R1.2, R2.2, R3.1
BUS_N: C2.2, CN1.2, CN1.3, MOV2.1, R2.1
BUS_P: C1.2, CN1.1, CN1.4, MOV1.1, R1.1
CCOMP: C4.1, C5.1, U1.21 (CCOMP)
CMC_N: C2.1, L1.3
CMC_P: C1.1, L1.4
GND: C3.2, C4.2, C5.2, C6.2, C7.2, C8.2, C9.2, C10.2, C11.2, C12.2, C13.2, C14.2, C15.2, C16.2, J1.6 (GND), J1.9 (GND), J1.14 (GND), J1.20 (GND), J1.25 (GND), J1.30 (GND), J1.34 (GND), J1.39 (GND), MOV1.2, MOV2.2, R3.2, R7.2, U1.2 (VSS), U1.3 (VSS), U1.5 (VSS), U1.14 (DIOB1), U1.16 (DIOB0), U1.20 (DIOA2), U1.22 (DIOA3), U1.23 (DIOA4), U1.32 (WAKE_IN), U1.33 (VSS_EP)
IRQ_N: J1.16 (GPIO23), R6.2, U1.9 (IRQ_N)
LED0_A: D1.2 (A), R8.2
LED0_K: D1.1 (K), U1.18 (DIOA0)
LED1_A: D2.2 (A), R9.2
LED1_K: D2.1 (K), U1.19 (DIOA1)
RBIAS: R7.1, U1.26 (RBIAS)
RESET_N: J1.15 (GPIO22), R4.2, U1.8 (RESET_N)
SPI_CS_N: J1.24 (GPIO8/CE0), R5.2, U1.11 (CS_N)
SPI_MISO: J1.21 (GPIO9/MISO), U1.10 (SDO)
SPI_MOSI: J1.19 (GPIO10/MOSI), U1.13 (SDI)
SPI_SCLK: J1.23 (GPIO11/SCLK), U1.12 (SCLK)
TRXN: L1.2, U1.31 (TRXN)
TRXP: L1.1, U1.30 (TRXP)
VDDA: C11.1, C12.1, FB1.2, U1.29 (VDDA)
VDDAU: C13.1, C14.1, FB2.2, U1.25 (VDDAU)
VDDP: C7.1, C8.1, FB3.2, JP1.1, U1.4 (TEST), U1.7 (VDDP)
VDDP_17: C9.1, C10.1, JP1.2, U1.17 (VDDP)
XTI: C16.1, U1.27 (XTI), Y1.1
XTO: C15.1, U1.28 (XTO), Y1.2

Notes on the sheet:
T1S HAT for LilyGO T-ETH-Elite - Microchip LAN8651 10BASE-T1S MAC-PHY
Every value is from ELECTRICAL.md (Microchip DS60001734F / AN1718 DS60001718D). Single 3.3 V rail: the LAN8651 regulates its own 1.8 V core.
SUPPLY + DECOUPLING 0.1uF and 0.01uF at EVERY power pin, 0.01uF nearest. FB1..3 are the data sheet's optional supply-island beads, fitted as 0R.
JP1 - 0 ohm link. VDDP is one supply island; on two layers its two halves need one crossing, and JP1 is it. FITTED.
BUS INTERFACE NETWORK (AN1718 MINIMAL BIN) CMC - AC coupling - termination - ESD - MDI connector
R1/R2 SHIP UNSTUFFED. Fit 49R9 1% 1W for an END-OF-BUS node, or 1K5 1% for an interior DROP node.
CLOCK 25.000 MHz, CL 18 pF. No series and no feedback resistor: the device has ~1 Mohm internally across the amplifier.
STATUS LEDs on DIOA0/DIOA1 (VDDP domain, 1k to 3V3; the DIO sinks). DIOA2/3/4 and DIOB0/DIOB1 to ground.
PWR_FLAG: these rails are fed through passive pins (header pads, 0R beads), so ERC is told where the supply enters.

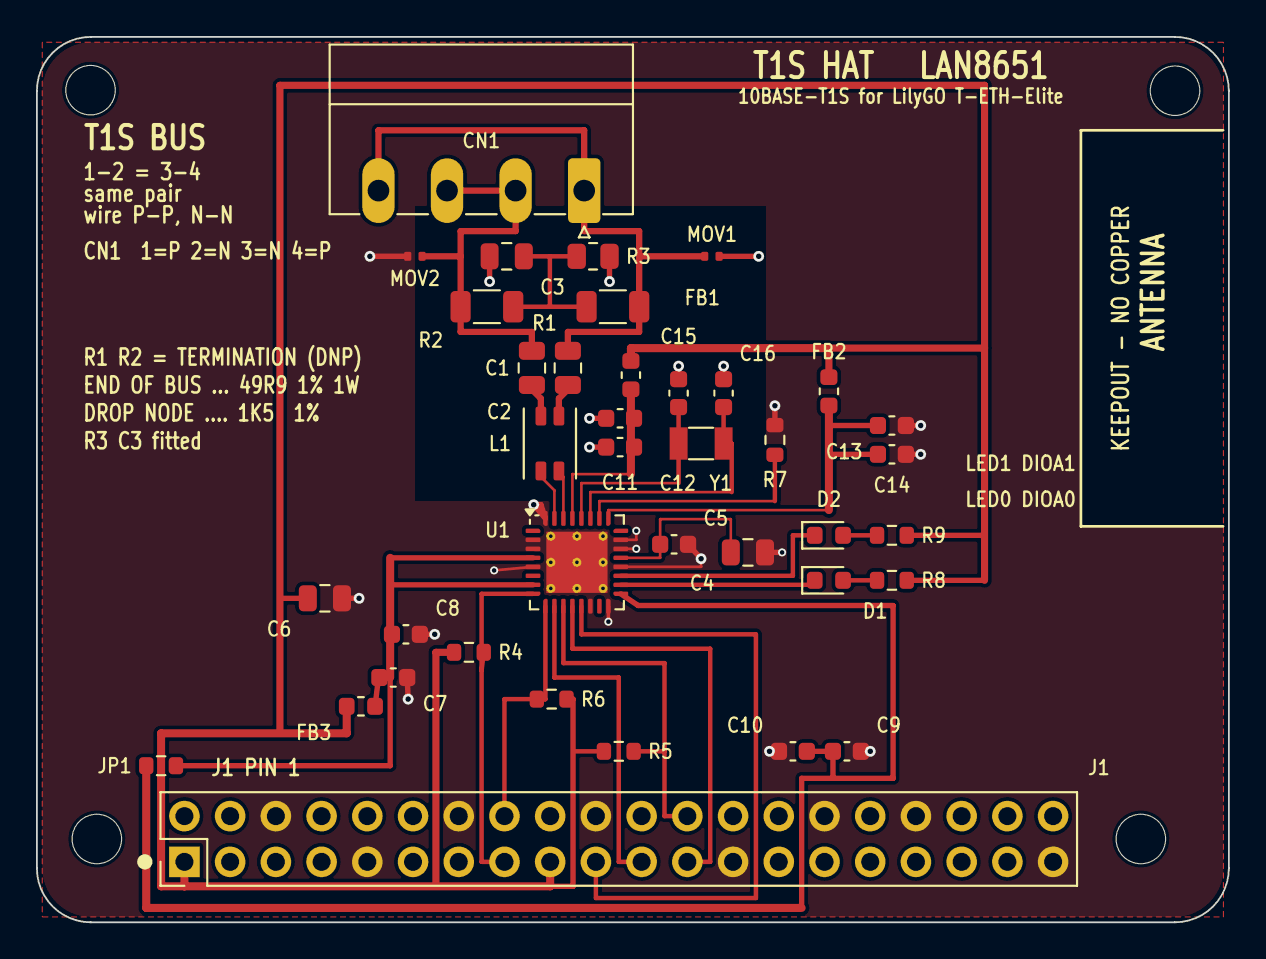
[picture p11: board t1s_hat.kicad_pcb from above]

Board: 2 copper layers, 66.2 x 49.2 mm, 42 parts (0 on the bottom side), 27 nets.

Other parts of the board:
H1, H2, H3, H4: NPTH_2.75mm

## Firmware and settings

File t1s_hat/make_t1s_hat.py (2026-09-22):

#!/usr/bin/env python3
"""
Generate the T1S HAT: symbol library, schematic, PCB, and all fab outputs.

Run:  python3 make_t1s_hat.py      (KiCad 7 pcbnew Python bindings required)

Sources of truth, in this order:
  ../pcb/GEOMETRY.md   mechanical   (outline, holes, 2x20 grid) -- inherited
  ELECTRICAL.md        electrical   (every part, value and pin rule)

Nothing in either file is re-derived here.  Deviations from them that were
directed by the project owner after those files were written are marked
"DIRECTED:" in the comments and are listed in README.md.

COORDINATE FRAME -- read before touching a number
-------------------------------------------------
GEOMETRY.md's frame ("G frame"): T-ETH-Elite top view, origin at the Elite's
PCB bottom-left corner, +x right, +y UP.  KiCad's PCB frame has +y DOWN.
The single conversion is kx()/ky()/V(); the G origin sits at KiCad (100,100).
Same convention as ../pcb/make_board.py, from which the mechanical code here
is reused.
"""

import csv
import json
import math
import os
import re
import subprocess
import sys
import uuid as _uuid
import zipfile

import pcbnew

HERE = os.path.dirname(os.path.abspath(__file__))
NAME = "t1s_hat"
PCB_PATH = os.path.join(HERE, NAME + ".kicad_pcb")
SCH_PATH = os.path.join(HERE, NAME + ".kicad_sch")
PRO_PATH = os.path.join(HERE, NAME + ".kicad_pro")
SYMDIR = os.path.join(HERE, "sym")
SYMLIB = os.path.join(SYMDIR, "t1s_hat.kicad_sym")
FPDIR = os.path.join(HERE, "fp", "t1s_hat.pretty")

KSYM = "/usr/share/kicad/symbols/"
KFP = "/usr/share/kicad/footprints/"


def fp_dir(lib):
    """Directory holding footprint library `lib`.  Project-local parts live in
    fp/t1s_hat.pretty; everything else comes from the KiCad install."""
    return FPDIR if lib == "t1s_hat" else KFP + lib + ".pretty"

# ---------------------------------------------------------------- frame ----
ORIGIN_X = 100.0
ORIGIN_Y = 100.0


def kx(gx):
    return ORIGIN_X + gx


def ky(gy):
    return ORIGIN_Y - gy


def V(gx, gy):
    return pcbnew.VECTOR2I(pcbnew.FromMM(kx(gx)), pcbnew.FromMM(ky(gy)))


def MM(v):
    return pcbnew.FromMM(v)


def SZ(w, h):
    return pcbnew.VECTOR2I(pcbnew.FromMM(w), pcbnew.FromMM(h))


def gof(pt):
    """KiCad VECTOR2I -> G-frame (x, y) in mm."""
    return (pcbnew.ToMM(pt.x) - ORIGIN_X, ORIGIN_Y - pcbnew.ToMM(pt.y))


# ------------------------------------------------- GEOMETRY.md mechanical --
# DIRECTED: the RJ45 notch is dropped; this board is lifted clear of the jack
# by a taller riser instead, so the outline is the plain rectangle.  Every
# other mechanical number below is GEOMETRY.md's, unchanged.
BOARD_W = 66.22
BOARD_H = 49.19
CORNER_R = 3.0
BOARD_T = 1.6

HOLE_D = 2.75
HOLES = [
    ("H1", 3.33, 4.63, "T-ETH-Elite bottom-left"),
    ("H2", 61.33, 4.63, "T-ETH-Elite bottom-right"),
    ("H3", 2.98, 46.23, "T-ETH-Elite top-left"),
    ("H4", 63.23, 46.20, "T-ETH-Elite top-right"),
]

HDR_X0 = 8.196
HDR_PITCH = 2.54
HDR_ROW_ODD = 3.360
HDR_ROW_EVEN = 5.900


def pin_xy(pin):
    """G-frame (x, y) of 40-pin header pin `pin` (1..40)."""
    k = (pin - 1) // 2
    return HDR_X0 + HDR_PITCH * k, (HDR_ROW_ODD if pin % 2 else HDR_ROW_EVEN)


# ELECTRICAL.md: the Elite's WROOM antenna sits under this board here.
KEEPOUT = (58.0, 22.0, 66.22, 44.0)       # x0, y0, x1, y1

EDGE_W = 0.10
SILK_W = 0.15


# ===========================================================================
#  THE CIRCUIT -- one table, used for the symbol library, the schematic and
#  the PCB, so the three cannot disagree.
# ===========================================================================

# LAN8651, 32-VQFN 5x5, exposed pad = VSS.  Pin table verbatim from
# ELECTRICAL.md.  Columns: number, name, electrical type, symbol side.
#   side: L/R/T/B on the schematic symbol body.
LAN8651_PINS = [
    # --- host SPI + reset, left of the symbol -----------------------------
    (11, "CS_N",     "input",          "L", 22.86),
    (12, "SCLK",     "input",          "L", 20.32),
    (13, "SDI",      "input",          "L", 17.78),
    (10, "SDO",      "output",         "L", 15.24),
    (9,  "IRQ_N",    "open_collector", "L", 12.70),
    (8,  "RESET_N",  "input",          "L",  7.62),
    # --- config / analogue, left ------------------------------------------
    (4,  "TEST",     "input",          "L",  2.54),
    (27, "XTI",      "passive",        "L", -2.54),
    (28, "XTO",      "output",         "L", -5.08),
    (26, "RBIAS",    "passive",        "L", -10.16),
    (21, "CCOMP",    "passive",        "L", -12.70),
    # --- bus, right --------------------------------------------------------
    (30, "TRXP",     "bidirectional",  "R", 22.86),
    (31, "TRXN",     "bidirectional",  "R", 20.32),
    # --- configurable IO, right -------------------------------------------
    (18, "DIOA0",    "bidirectional",  "R", 15.24),
    (19, "DIOA1",    "bidirectional",  "R", 12.70),
    (20, "DIOA2",    "bidirectional",  "R", 10.16),
    (22, "DIOA3",    "bidirectional",  "R",  7.62),
    (23, "DIOA4",    "bidirectional",  "R",  5.08),
    (16, "DIOB0",    "bidirectional",  "R",  2.54),
    (14, "DIOB1",    "bidirectional",  "R",  0.00),
    # --- power management / unused, right ---------------------------------
    (32, "WAKE_IN",  "input",          "R", -5.08),
    (24, "WAKE_OUT", "output",         "R", -7.62),
    (1,  "INH",      "open_collector", "R", -10.16),
    (6,  "DNC",      "passive",        "R", -15.24),
    (15, "DNC",      "passive",        "R", -17.78),
    # --- supplies, top -----------------------------------------------------
    (7,  "VDDP",     "power_in",       "T", -7.62),
    (17, "VDDP",     "power_in",       "T", -2.54),
    (29, "VDDA",     "power_in",       "T",  2.54),
    (25, "VDDAU",    "power_in",       "T",  7.62),
    # --- grounds, bottom ---------------------------------------------------
    (2,  "VSS",      "power_in",       "B", -7.62),
    (3,  "VSS",      "power_in",       "B", -2.54),
    (5,  "VSS",      "power_in",       "B",  2.54),
    (33, "VSS_EP",   "power_in",       "B",  7.62),
]

# The 40-pin host header.  Pin electrical types say who drives what: this is
# the ESP32-S3 side, so the six signals ELECTRICAL.md assigns are declared
# output/input accordingly and the rest are passive.  Names are the Raspberry
# Pi names, which is what ELECTRICAL.md's host-interface table uses.
RPI_NAMES = {
    1: "3V3", 2: "5V", 3: "GPIO2/SDA1", 4: "5V", 5: "GPIO3/SCL1", 6: "GND",
    7: "GPIO4", 8: "GPIO14/TXD", 9: "GND", 10: "GPIO15/RXD", 11: "GPIO17",
    12: "GPIO18", 13: "GPIO27", 14: "GND", 15: "GPIO22", 16: "GPIO23",
    17: "3V3", 18: "GPIO24", 19: "GPIO10/MOSI", 20: "GND", 21: "GPIO9/MISO",
    22: "GPIO25", 23: "GPIO11/SCLK", 24: "GPIO8/CE0", 25: "GND",
    26: "GPIO7/CE1", 27: "ID_SD", 28: "ID_SC", 29: "GPIO5", 30: "GND",
    31: "GPIO6", 32: "GPIO12", 33: "GPIO13", 34: "GND", 35: "GPIO19",
    36: "GPIO16", 37: "GPIO26", 38: "GPIO20", 39: "GND", 40: "GPIO21",
}
HDR_DRIVEN = {15: "output", 16: "input", 19: "output", 21: "input",
              23: "output", 24: "output"}
HDR_GND = [6, 9, 14, 20, 25, 30, 34, 39]
HDR_3V3 = [1, 17]

# Net attached to each header pin; None => no-connect.
HDR_NET = {}
for _p in range(1, 41):
    HDR_NET[_p] = None
for _p in HDR_GND:
    HDR_NET[_p] = "GND"
for _p in HDR_3V3:
    HDR_NET[_p] = "+3V3"
HDR_NET.update({15: "RESET_N", 16: "IRQ_N", 19: "SPI_MOSI",
                21: "SPI_MISO", 23: "SPI_SCLK", 24: "SPI_CS_N"})

# LAN8651 pin -> net; None => no-connect (no copper stub either).
U1_NET = {
    1: None,            # INH   DS60001734F Tbl 3-5: "left unconnected" if unused
    2: "GND", 3: "GND", 5: "GND",
    4: "VDDP",          # TEST  "must be connected to VDDP"
    6: None, 15: None,  # DNC   "must be left floating externally"
    # VDDP is one supply island, but on one layer its two halves cannot be
    # joined without one crossing (see build_routes / README), so the pin-17
    # half is its own net VDDP_17, linked to VDDP by the 0 ohm jumper JP1.
    7: "VDDP", 17: "VDDP_17",
    8: "RESET_N", 9: "IRQ_N", 10: "SPI_MISO", 11: "SPI_CS_N",
    12: "SPI_SCLK", 13: "SPI_MOSI",
    14: "GND", 16: "GND",          # DIOB1 "connected directly to ground"
    18: "LED0_K", 19: "LED1_K",
    20: "GND", 22: "GND", 23: "GND",   # DIOA2/3/4 unused -> ground
    21: "CCOMP",
    24: None,           # WAKE_OUT "should be left unconnected"
    25: "VDDAU", 26: "RBIAS", 27: "XTI", 28: "XTO", 29: "VDDA",
    30: "TRXP", 31: "TRXN",
    32: "GND",          # WAKE_IN  "should be connected to VSS"
    33: "GND",          # exposed pad
}

FP_C0603 = "Capacitor_SMD:C_0603_1608Metric"
FP_C0805 = "Capacitor_SMD:C_0805_2012Metric"
FP_R0603 = "Resistor_SMD:R_0603_1608Metric"
FP_R0805 = "Resistor_SMD:R_0805_2012Metric"
FP_R1206 = "Resistor_SMD:R_1206_3216Metric"
FP_L0603 = "Inductor_SMD:L_0603_1608Metric"
FP_LED = "LED_SMD:LED_0603_1608Metric"
FP_MOV = "t1s_hat:Varistor_TDK_AVRH10_1005"

# ---------------------------------------------------------------------------
# PARTS.  Each entry:
#   ref, lib_id, value, footprint, {pin: net}, (pcb_x, pcb_y, pcb_rot),
#   (sch_x, sch_y), dnp, description, lcsc
# pcb_rot is in KiCad degrees and is checked by reading the pads back.
# ---------------------------------------------------------------------------
P = []


def part(ref, lib_id, value, fp, nets, pcb, sch, dnp=False, descr="", lcsc=""):
    P.append(dict(ref=ref, lib_id=lib_id, value=value, fp=fp, nets=nets,
                  pcb=pcb, sch=sch, dnp=dnp, descr=descr, lcsc=lcsc))


part("U1", "t1s_hat:LAN8651",
     "LAN8651",
     "Package_DFN_QFN:TQFN-32-1EP_5x5mm_P0.5mm_EP3.4x3.4mm_ThermalVias",
     U1_NET, (30.0, 20.0, 0), (175.0, 130.0),
     descr="Microchip LAN8651 10BASE-T1S MAC-PHY, OPEN Alliance TC6 SPI, "
           "32-VQFN 5x5 (internal 1.8 V core LDO -> single 3.3 V rail)")

part("J1", "t1s_hat:HAT_HEADER_2x20",
     "2x20 socket (riser stack)",
     "Connector_PinHeader_2.54mm:PinHeader_2x20_P2.54mm_Vertical",
     HDR_NET, (0, 0, 0), (60.0, 120.0),
     descr="2x20 2.54 mm THT socket; mates with the riser that plugs onto "
           "the T-ETH-Elite's own 9.30 mm header pins")

# --- bus interface network, AN1718 order: CMC - caps - term - ESD - CN1 -----
# L1: TDK ACT1210L-201-2P-TL00.  AN1718 names ACT1210D-131 / ACT1210E-241 /
# Murata DLW32MH241MX2 as EXAMPLES ("exact part numbers ... must be determined
# by the customer's unique application"), all 130...240 uH @ 100 kHz in a
# 3.2 x 2.5 mm package.  The -201 is the same ACT1210 package at 200 uH, inside
# that span, AEC-Q200, and -- unlike the three examples -- stocked at LCSC
# (C131444), which is where this board gets built.  Windings are 1-4 and 2-3.
part("L1", "Device:L_Coupled_1423", "200uH @ 100kHz CMC",
     "t1s_hat:L_CommonMode_TDK_ACT1210_3225",
     {1: "TRXP", 2: "TRXN", 3: "CMC_N", 4: "CMC_P"},
     (28.5, 26.6, 90), (250.0, 100.0), lcsc="C131444",
     descr="Common-mode choke, 2-line, 200 uH @ 100 kHz, EIA 1210 "
           "(3.2x2.5 mm), AEC-Q200 - TDK ACT1210L-201-2P-TL00 (AN1718 L1). "
           "ALWAYS FITTED.")
part("C1", "Device:C", "100nF/100V", FP_C0805,
     {1: "CMC_P", 2: "BUS_P"}, (29.5, 30.8, 90), (250.0, 118.0),
     descr="AC coupling / galvanic isolation, bus P. ALWAYS FITTED (AN1718)")
part("C2", "Device:C", "100nF/100V", FP_C0805,
     {1: "CMC_N", 2: "BUS_N"}, (27.5, 30.8, 90), (250.0, 136.0),
     descr="AC coupling / galvanic isolation, bus N. ALWAYS FITTED (AN1718)")
part("R1", "Device:R", "49R9 1% 1W (DNP)", FP_R1206,
     {1: "BUS_P", 2: "BUS_CT"}, (32, 34.2, 180), (288.0, 112.0), dnp=True,
     descr="Bus termination, P leg. 49R9 1% 1W for an END node, 1K5 1% for "
           "a DROP node. Shipped unstuffed - see README.")
part("R2", "Device:R", "49R9 1% 1W (DNP)", FP_R1206,
     {1: "BUS_N", 2: "BUS_CT"}, (25, 34.2, 0), (288.0, 142.0), dnp=True,
     descr="Bus termination, N leg. 49R9 1% 1W for an END node, 1K5 1% for "
           "a DROP node. Shipped unstuffed - see README.")
part("R3", "Device:R", "100k 5%", FP_R0805,
     {1: "BUS_CT", 2: "GND"}, (30.9, 37, 0), (300.0, 127.0),
     descr="Common-mode termination, centre tap to ground (AN1718 R3)")
part("C3", "Device:C", "100nF/100V", FP_C0805,
     {1: "BUS_CT", 2: "GND"}, (26.1, 37, 180), (312.0, 127.0),
     descr="Common-mode termination, centre tap to ground (AN1718 C3)")
# MOV1/MOV2: the part ELECTRICAL.md already names, TDK AVRH10C221KT1R5YA8 --
# a 1005 [0402] chip varistor, 220 V V1mA, 1.5 pF, 25 kV IEC61000-4-2, not the
# 1206 land this board used to infer.  LCSC C2157827.
part("MOV1", "Device:Varistor", "22V 1.5pF ESD (DNP)", FP_MOV,
     {1: "BUS_P", 2: "GND"}, (37.5, 37, 0), (330.0, 112.0), dnp=True,
     lcsc="C2157827",
     descr="ESD element on bus P, at the connector (AN1718 MOV1) - TDK "
           "AVRH10C221KT1R5YA8 chip varistor, 1005 [0402], 1.5 pF. Optional.")
part("MOV2", "Device:Varistor", "22V 1.5pF ESD (DNP)", FP_MOV,
     {1: "BUS_N", 2: "GND"}, (21, 37, 180), (330.0, 142.0), dnp=True,
     lcsc="C2157827",
     descr="ESD element on bus N, at the connector (AN1718 MOV2) - TDK "
           "AVRH10C221KT1R5YA8 chip varistor, 1005 [0402], 1.5 pF. Optional.")
part("CN1", "Connector_Generic:Conn_01x04", "T1S BUS  P N N P",
     "Connector_Phoenix_MC:PhoenixContact_MC_1,5_4-G-3.81_1x04_"
     "P3.81mm_Horizontal",
     {1: "BUS_P", 2: "BUS_N", 3: "BUS_N", 4: "BUS_P"},
     # 0.35 mm in from y = 41: the body outline otherwise lands 0.02 mm from
     # Edge.Cuts and the silk is clipped at the board edge.
     (30.405, 40.65, 180), (360.0, 127.0),
     descr="MDI connector, 4-pin 3.81 mm pluggable terminal block. "
           "Pins 1..4 = P N N P; the two P and the two N are shorted on "
           "board so the node taps a daisy chain.")

# --- clock -----------------------------------------------------------------
part("Y1", "Device:Crystal", "25.000MHz",
     "Crystal:Crystal_SMD_3215-2Pin_3.2x1.5mm",
     {1: "XTI", 2: "XTO"}, (36.9, 26.6, 0), (120.0, 170.0),
     descr="25.000 MHz fundamental parallel-resonant crystal, CL 18 pF, "
           "low ESR. No series or feedback resistor (data sheet).")
part("C15", "Device:C", "18pF", FP_C0603,
     {1: "XTO", 2: "GND"}, (35.65, 29.4, 90), (104.0, 178.0),
     descr="Crystal load capacitor C1 (data sheet: C1 = C2 = 18 pF)")
part("C16", "Device:C", "18pF", FP_C0603,
     {1: "XTI", 2: "GND"}, (38.15, 29.4, 90), (136.0, 178.0),
     descr="Crystal load capacitor C2 (data sheet: C1 = C2 = 18 pF)")

# --- analogue reference ----------------------------------------------------
part("R7", "Device:R", "12k4 1%", FP_R0603,
     {1: "RBIAS", 2: "GND"}, (41.0, 26.8, 90), (120.0, 200.0),
     descr="RBIAS. 12.4 kohm 1% over the whole operating temperature range "
           "- no substitutions (data sheet).")

# --- supplies --------------------------------------------------------------
part("FB1", "Device:FerriteBead", "0R (FB opt.)", FP_L0603,
     {1: "+3V3", 2: "VDDA"}, (33.0, 30.4, 270), (60.0, 60.0),
     descr="VDDA supply island option: 0 ohm fitted; may be replaced by a "
           "~300 ohm @ 100 MHz bead (e.g. Wuerth 742792640).")
part("FB2", "Device:FerriteBead", "0R (FB opt.)", FP_L0603,
     {1: "+3V3", 2: "VDDAU"}, (44, 29.5, 270), (60.0, 90.0),
     descr="VDDAU supply island option: 0 ohm fitted.")
part("FB3", "Device:FerriteBead", "0R (FB opt.)", FP_L0603,
     {1: "+3V3", 2: "VDDP"}, (18, 12, 0), (60.0, 30.0),
     descr="VDDP supply island option: 0 ohm fitted.")
part("C6", "Device:C", "10uF", FP_C0805,
     {1: "+3V3", 2: "GND"}, (16, 18, 0), (40.0, 45.0),
     descr="Bulk decoupling on the 3.3 V supply side")

# per-pin decoupling: 0.1 uF + 0.01 uF at EACH power pin, 0.01 nearest
part("C7", "Device:C", "100nF", FP_C0603,
     {1: "VDDP", 2: "GND"}, (19.8, 13.6, 0), (90.0, 45.0),
     descr="VDDP (pin 7) decoupling, 0.1 uF")
part("C8", "Device:C", "10nF", FP_C0603,
     {1: "VDDP", 2: "GND"}, (20.5, 16, 0), (105.0, 45.0),
     descr="VDDP (pin 7) decoupling, 0.01 uF - closest to the pin")
part("C9", "Device:C", "100nF", FP_C0603,
     {1: "VDDP_17", 2: "GND"}, (45, 9.5, 0), (120.0, 45.0),
     descr="VDDP (pin 17) decoupling, 0.1 uF")
part("C10", "Device:C", "10nF", FP_C0603,
     {1: "VDDP_17", 2: "GND"}, (42, 9.5, 180), (135.0, 45.0),
     descr="VDDP (pin 17) decoupling, 0.01 uF - closest to the pin")
# C11/C12 sit 0.8 mm further out than the QFN would like so that their ground
# stitching vias clear the all-layer void under the choke, which grew when L1
# went to its real 3.2 x 2.5 mm body.
part("C11", "Device:C", "100nF", FP_C0603,
     {1: "VDDA", 2: "GND"}, (32.4, 28, 180), (150.0, 45.0),
     descr="VDDA (pin 29) decoupling, 0.1 uF")
part("C12", "Device:C", "10nF", FP_C0603,
     {1: "VDDA", 2: "GND"}, (32.4, 26.4, 180), (165.0, 45.0),
     descr="VDDA (pin 29) decoupling, 0.01 uF - closest to the pin")
part("C13", "Device:C", "100nF", FP_C0603,
     {1: "VDDAU", 2: "GND"}, (47.5, 27.6, 0), (180.0, 45.0),
     descr="VDDAU (pin 25) decoupling, 0.1 uF")
part("C14", "Device:C", "10nF", FP_C0603,
     {1: "VDDAU", 2: "GND"}, (47.5, 26, 0), (195.0, 45.0),
     descr="VDDAU (pin 25) decoupling, 0.01 uF - closest to the pin")
part("C4", "Device:C", "4.7uF low-ESR", FP_C0805,
     {1: "CCOMP", 2: "GND"}, (39.5, 20.55, 0), (215.0, 45.0),
     descr="CCOMP: internal +1.8 V core LDO compensation. REQUIRED, low ESR, "
           "to the ground plane (LAN8651 only).")
part("C5", "Device:C", "100nF", FP_C0603,
     {1: "CCOMP", 2: "GND"}, (35.4, 21, 0), (232.0, 45.0),
     descr="CCOMP support capacitor (data sheet: useful, not required)")

# --- host-side pull-ups ----------------------------------------------------
part("R4", "Device:R", "10k", FP_R0603,
     {1: "+3V3", 2: "RESET_N"}, (24, 15, 0), (95.0, 95.0),
     descr="RESET_N pull-up: a floating host GPIO during ESP32 boot must not "
           "hold the PHY in reset")
# R5 straddles the SPI_MISO column: MISO runs between its two pads, so the
# resistor that has to be in the CS_N path anyway is also the layer crossing
# that path needs.  0603 pads are 0.85 mm apart, a 0.25 mm track leaves
# 0.30 mm a side.  See README, "Two crossings on one layer".
part("R5", "Device:R", "10k", FP_R0603,
     {1: "+3V3", 2: "SPI_CS_N"}, (32.326, 9.5, 0), (95.0, 105.0),
     descr="SPI CS_N pull-up; also the F.Cu crossover for SPI_MISO, which "
           "passes between its pads")
part("R6", "Device:R", "10k", FP_R0603,
     {1: "+3V3", 2: "IRQ_N"}, (28.6, 12.4, 180), (95.0, 115.0),
     descr="IRQ_N pull-up (open-drain capable interrupt output)")

# --- status LEDs -----------------------------------------------------------
part("R8", "Device:R", "1k", FP_R0603,
     {1: "+3V3", 2: "LED0_A"}, (47.5, 19, 180), (330.0, 60.0),
     descr="LED0 series resistor to 3V3 (DIOA0 sinks)")
part("D1", "Device:LED", "GRN", FP_LED,
     {2: "LED0_A", 1: "LED0_K"}, (44, 19, 0), (345.0, 60.0),
     descr="Status LED 0 on DIOA0 - firmware maps it (e.g. PLCA status)")
part("R9", "Device:R", "1k", FP_R0603,
     {1: "+3V3", 2: "LED1_A"}, (47.5, 21.5, 180), (330.0, 75.0),
     descr="LED1 series resistor to 3V3 (DIOA1 sinks)")
part("D2", "Device:LED", "YEL", FP_LED,
     {2: "LED1_A", 1: "LED1_K"}, (44, 21.5, 0), (345.0, 75.0),
     descr="Status LED 1 on DIOA1 - firmware maps it (e.g. activity)")

# --- layer crossing ---------------------------------------------------------
# DIRECTED: a deliberate 0 ohm jumper, not an oversight.  VDDP's pin-7 island
# is fenced in by the +3V3 tree, the header and the SPI fan-out; on one signal
# layer exactly one crossing is unavoidable, and B.Cu is not available for it
# (the uninterrupted bottom pour is what buys back the fourth layer here).
# JP1 straddles the +3V3 branch that runs up the left edge: +3V3 passes
# between its two pads.
part("JP1", "Device:R", "0R jumper", FP_R0603,
     {1: "VDDP", 2: "VDDP_17"}, (6.90, 8.70, 180), (110.0, 80.0),
     descr="0 ohm link, VDDP pin-7 island to VDDP pin-17 island. The 2-layer "
           "crossover for +3V3, which passes between its pads. FITTED - the "
           "board does not work without it.")

BY_REF = {p["ref"]: p for p in P}

# Nets that get a PWR_FLAG on the schematic: their only drivers on this board
# are passive (the header, or a 0 ohm bead), so ERC needs to be told they are
# supplies.
PWR_FLAG_NETS = ["+3V3", "GND", "VDDP", "VDDP_17", "VDDA", "VDDAU"]


# ===========================================================================
#  SYMBOL LIBRARY -- LAN8651 (no KiCad symbol exists) + the host header
# ===========================================================================
FONT = '(effects (font (size 1.27 1.27)))'


def _pin(etype, x, y, ang, length, name, number, hide=False):
    h = " hide" if hide else ""
    return ('      (pin %s line (at %.4f %.4f %d) (length %.2f)%s\n'
            '        (name "%s" (effects (font (size 1.27 1.27))))\n'
            '        (number "%s" (effects (font (size 1.27 1.27))))\n'
            '      )\n' % (etype, x, y, ang, length, h, name, number))


def _rect(x1, y1, x2, y2):
    return ('      (rectangle (start %.3f %.3f) (end %.3f %.3f)\n'
            '        (stroke (width 0.254) (type default))\n'
            '        (fill (type background))\n'
            '      )\n' % (x1, y1, x2, y2))


def _prop(key, val, x, y, hide=False, just=None):
    e = '(effects (font (size 1.27 1.27))'
    if just:
        e += ' (justify %s)' % just
    if hide:
        e += ' hide'
    e += ')'
    return '      (property "%s" "%s" (at %.3f %.3f 0)\n        %s\n      )\n' \
        % (key, val, x, y, e)
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

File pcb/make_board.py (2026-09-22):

#!/usr/bin/env python3
"""
Generate t_eth_elite_hat_adapter.kicad_pcb from the numbers in GEOMETRY.md.

Run:  python3 make_board.py          (KiCad 7 pcbnew Python bindings required)

Why a generator and not a hand-drawn board: every coordinate here comes from
GEOMETRY.md, which was measured from LilyGo's own DXF/3D CAD.  A script lands
those numbers exactly, can be re-run when one of them changes, and diffs
legibly.  GEOMETRY.md is the source of truth; if this file and that file ever
disagree, that file is right.

--------------------------------------------------------------------------
COORDINATE FRAME  --  read this before touching any number below
--------------------------------------------------------------------------
GEOMETRY.md's frame ("G frame"): T-ETH-Elite top view, origin at the Elite's
PCB bottom-left corner, +x right, +y UP.  KiCad's PCB frame has +y DOWN.

The single conversion is kx()/ky()/V() below:

    kicad_x = ORIGIN_X + gx
    kicad_y = ORIGIN_Y - gy

i.e. the G frame origin (0, 0) sits at KiCad (100, 100) mm, and the board
occupies KiCad x 100.00..166.22, y 42.80..100.00.  Nothing else in this file
converts coordinates; every feature is specified in G-frame mm and passed
through V().  Angles: a G-frame CCW angle is a KiCad CW angle, which matters
only for the header footprint, and that is resolved empirically (see
place_header) rather than by reasoning about the sign.
--------------------------------------------------------------------------
"""

import csv
import json
import os
import re
import subprocess
import sys
import zipfile

import pcbnew

HERE = os.path.dirname(os.path.abspath(__file__))
NAME = "t_eth_elite_hat_adapter"
PCB_PATH = os.path.join(HERE, NAME + ".kicad_pcb")
PRO_PATH = os.path.join(HERE, NAME + ".kicad_pro")

# ---------------------------------------------------------------- frame ----
ORIGIN_X = 100.0
ORIGIN_Y = 100.0


def kx(gx):
    """G-frame x -> KiCad x (mm)."""
    return ORIGIN_X + gx


def ky(gy):
    """G-frame y (+up) -> KiCad y (+down) (mm)."""
    return ORIGIN_Y - gy


def V(gx, gy):
    """G-frame point -> KiCad VECTOR2I (internal units)."""
    return pcbnew.VECTOR2I(pcbnew.FromMM(kx(gx)), pcbnew.FromMM(ky(gy)))


def MM(v):
    return pcbnew.FromMM(v)


def SZ(w, h):
    return pcbnew.VECTOR2I(pcbnew.FromMM(w), pcbnew.FromMM(h))


# ------------------------------------------------------- GEOMETRY.md data --
# Outline: 0..66.22 in x, 0..57.20 in y, 3 mm rounded corners.
BOARD_W = 66.22
BOARD_H = 57.20
CORNER_R = 3.0

# RJ45 clearance notch: rectangular bite out of the left edge.
NOTCH_X1, NOTCH_Y0, NOTCH_Y1 = 17.40, 10.00, 29.40

# 6 mounting holes, all Ø2.75, non-plated.
HOLE_D = 2.75
HOLES = [
    ("H1", 3.33, 4.63, "T-ETH-Elite bottom-left AND HAT near-left"),
    ("H2", 61.33, 4.63, "T-ETH-Elite bottom-right AND HAT near-right"),
    ("H3", 2.98, 46.23, "T-ETH-Elite top-left"),
    ("H4", 63.23, 46.20, "T-ETH-Elite top-right"),
    ("H5", 3.33, 53.63, "HAT far-left"),
    ("H6", 61.33, 53.63, "HAT far-right"),
]

# Tool-access holes for the Elite's two ST-1133 tactile switches, which this
# board would otherwise bury.  Centres are the midpoints of the switch
# footprints in LilyGo's CAD (x 41.48..45.98 and 52.10..56.60, y 45.85..49.35).
# Ø4.0 is a tweezer/pen tip, not a finger.
TOOL_D = 4.0
TOOL_HOLES = [
    ("H7", 43.73, 47.60, "BOOT", "tool access to the Elite's SW4 BOOT button"),
    ("H8", 54.35, 47.60, "RST", "tool access to the Elite's SW5 EN/RESET button"),
]

# 2x20 THT stacking header.  Pin grid from GEOMETRY.md.
HDR_X0 = 8.196
HDR_PITCH = 2.54
HDR_ROW_ODD = 3.360   # row nearer the board's y=0 edge
HDR_ROW_EVEN = 5.900
HDR_LIB = "/usr/share/kicad/footprints/Connector_PinHeader_2.54mm.pretty"
HDR_FP = "PinHeader_2x20_P2.54mm_Vertical"


def pin_xy(pin):
    """G-frame (x, y) of 40-pin header pin `pin` (1..40).

    Pin 1 is at the low-x end (nearest the RJ45 notch) on the row nearest the
    board's y=0 edge.  Odd pins on y=3.360, even pins on y=5.900.  See the
    README's "Which pin is pin 1" section for how this was established --
    GEOMETRY.md gives the grid but not the numbering.
    """
    k = (pin - 1) // 2
    return HDR_X0 + HDR_PITCH * k, (HDR_ROW_ODD if pin % 2 else HDR_ROW_EVEN)


# Standard Raspberry Pi 40-pin assignment.  (short silk label, table label)
RPI_PINS = {
    1: ("3V3", "3V3"),            2: ("5V", "5V"),
    3: ("SDA", "GPIO2 SDA1"),     4: ("5V", "5V"),
    5: ("SCL", "GPIO3 SCL1"),     6: ("GND", "GND"),
    7: ("GP4", "GPIO4"),          8: ("TXD", "GPIO14 TXD"),
    9: ("GND", "GND"),           10: ("RXD", "GPIO15 RXD"),
    11: ("GP17", "GPIO17"),      12: ("GP18", "GPIO18"),
    13: ("GP27", "GPIO27"),      14: ("GND", "GND"),
    15: ("GP22", "GPIO22"),      16: ("GP23", "GPIO23"),
    17: ("3V3", "3V3"),          18: ("GP24", "GPIO24"),
    19: ("MOSI", "GPIO10 MOSI"), 20: ("GND", "GND"),
    21: ("MISO", "GPIO9 MISO"),  22: ("GP25", "GPIO25"),
    23: ("SCLK", "GPIO11 SCLK"), 24: ("CE0", "GPIO8 CE0"),
    25: ("GND", "GND"),          26: ("CE1", "GPIO7 CE1"),
    27: ("IDSD", "GPIO0 ID_SD"), 28: ("IDSC", "GPIO1 ID_SC"),
    29: ("GP5", "GPIO5"),        30: ("GND", "GND"),
    31: ("GP6", "GPIO6"),        32: ("GP12", "GPIO12"),
    33: ("GP13", "GPIO13"),      34: ("GND", "GND"),
    35: ("GP19", "GPIO19"),      36: ("GP16", "GPIO16"),
    37: ("GP26", "GPIO26"),      38: ("GP20", "GPIO20"),
    39: ("GND", "GND"),          40: ("GP21", "GPIO21"),
}

EDGE_W = 0.10
SILK_W = 0.15


# ------------------------------------------------------------- primitives --
def add_seg(board, layer, p0, p1, width):
    s = pcbnew.PCB_SHAPE(board)
    s.SetShape(pcbnew.SHAPE_T_SEGMENT)
    s.SetStart(V(*p0))
    s.SetEnd(V(*p1))
    s.SetLayer(layer)
    s.SetWidth(MM(width))
    board.Add(s)
    return s


def add_arc(board, layer, p0, pmid, p1, width):
    s = pcbnew.PCB_SHAPE(board)
    s.SetShape(pcbnew.SHAPE_T_ARC)
    s.SetArcGeometry(V(*p0), V(*pmid), V(*p1))
    s.SetLayer(layer)
    s.SetWidth(MM(width))
    board.Add(s)
    return s


def add_poly(board, layer, pts, width, filled=True):
    s = pcbnew.PCB_SHAPE(board)
    s.SetShape(pcbnew.SHAPE_T_POLY)
    chain = pcbnew.SHAPE_LINE_CHAIN()
    for p in pts:
        chain.Append(V(*p))
    chain.SetClosed(True)
    poly = pcbnew.SHAPE_POLY_SET()
    poly.AddOutline(chain)
    s.SetPolyShape(poly)
    s.SetLayer(layer)
    s.SetWidth(MM(width))
    s.SetFilled(filled)
    board.Add(s)
    return s
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

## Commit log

2026-09-22 T-ETH-Elite <-> Pi HAT adapter: case, vendor models, measurement script
    Lets a Raspberry Pi HAT (specifically TSN Lab's LAN8651 10BASE-T1S HAT) run on
    a LilyGO T-ETH-Elite. The Elite's 40-pin header already matches the Pi GPIO
    assignment pin for pin and its bottom hole pair lands within 0.005mm of where a
    HAT's near holes must be, so the adapter carries no signal logic - it exists
    because the Elite's RJ45 stands 15.97mm off the PCB against header pins ending
    at 10.10mm, and because a HAT's far holes fall 4.4mm past the Elite's edge.
    - case/: printed base tray, generated by script and boolean-checked against
    LilyGo's own 3D model on every run (zero interference, 141422 vertices tested)
    - r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
    [T-ETH-ELite-LoRa-Shield-view.stl, T-ETH-ELite-view.stl, T-ETH-ELite.dxf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]
2026-09-22 Add the adapter PCB, and stop overstating why it is needed
    The board: 66.22 x 57.20, RJ45 notch, the Elite's four asymmetric holes plus
    the HAT's far pair, two Ø4 BOOT/RST access holes, one 2x20 stacking header,
    no traces. Generated by make_board.py from GEOMETRY.md and read back: 48 of 48
    features match to 0.00000 mm. DRC clean apart from 8 library-consistency
    notices on the inline-generated NPTH footprints.
    Correction to both READMEs: an earlier draft claimed a HAT physically cannot
    sit on the Elite without this board. That is too strong - a tall enough
    stacking header clears the RJ45 by itself. What it cannot do is carry the
    HAT's far mounting pair, which lands 4.4mm past the Elite's ed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
    [bom.csv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]
2026-09-22 T1S HAT: LAN8651 schematic, 2-layer PCB and fab outputs
    Our own 10BASE-T1S board for the T-ETH-Elite, replacing the bought HAT.
    Everything is generated by make_t1s_hat.py from ELECTRICAL.md and
    ../pcb/GEOMETRY.md; the script reads the board back and asserts every
    mechanical feature against GEOMETRY.md (worst error 0.00000 mm).
    New parts, because KiCad has neither: a LAN8651 symbol (33 pins incl. the
    exposed pad, grouped by function) and a 40-pin host header whose pins carry
    real electrical types, so ERC sees the SPI inputs as driven.
    Three things depart from the two spec files, on instruction, and are argued
    in README.md rather than silently applied:
    - 2 layers, not 4. At 12.5 MBd over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
    [bom.csv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]
2026-09-22 T1S HAT: real choke and varistor lands, both nets closed, silk cleaned
    The choke was the fabrication blocker. L1 sat on KiCad's 1206 4-terminal
    land (3.2 x 1.6 mm) while every part AN1718 names is 3.2 x 2.5 mm, so the
    real component's terminals missed the pads. AN1718 says its part numbers
    are examples and the customer picks, so pick one that can be bought:
    TDK ACT1210L-201-2P-TL00, 200 uH @ 100 kHz (inside the 130..240 uH span
    the three examples cover), AEC-Q200, LCSC C131444. Its land is drawn from
    TDK's own ACT1210 layout recommendation -- 4.1 x 1.6 mm overall, 2.0 and
    0.4 mm gaps -- into a new project footprint library, and the symbol moves
    to L_Coupled_1423 because the ACT1210's winding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
    [bom.csv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]
